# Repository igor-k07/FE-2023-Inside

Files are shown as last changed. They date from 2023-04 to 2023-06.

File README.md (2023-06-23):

# Структура репозитория:<br>
1.3D – папка содержащая 3D модели, которые использовались для создания робота<br>
2.Src –  папка с файлами, которые используются для описания в README.md<br>
3.Видео – папка содержит видео работа нашей модели, которая проезжает по полю квалификацию и файлик с названием: «ссылка на ютьюб». Это ссылка ведет на наше видео про обьяснение работы робота и его составных частей в общем плане.<br>
4.Код – папка содержит код, который используется при работе робота<br>
	4.1 kvalifikacia.py– файл который используется для проезда трассы на этапе квалификации. В нем считывается изображение с камеры и передается управляющее воздействие на пайборд<br>
	4.2 main.py – загружаем его на пайборд. В нем приводятся в работу компоненты подключенные к пайборду на основе сообщения полученного с расберри<br>
	4.3 final.py – код находится в папке Код, используется для проезда финальной трассы<br>
	4.4 autostart- программа, которая ззапускается при загрузке при загрузке системы на расберри. В ней мы импортируем нужный файл для заезда<br>
	4.5 start_robot.py – программа, которая позволяет соеденится по вай-фай с расберри, и загрузить на нее программу с ноутбука. С помощью неё также можно увидеть изображение с камеры для отладки.<br>
	4.6 robotAPI.py  - файл, в котором содержится класс для получения изображения с камеры и его обработки. <br>
5.Технический журнал – папка хранит в себе три файла формата docx, файлы представляют собой документации и тщательное обьяснение работы робота. <br>
6.Фото – папка содержит фотографию разработчиков робота.<br>
# Обьяснение кода<br>
main.py – файл формата python, загружается на пайборд, с целью управления нижней части робота или же ходовкой. Немало важный смысл программы, это прием сообщений с расберри, в сообщении храниться информация о том с какой скоростью должен ехать робот, с каким углом поворачивать и включение светодиода. Конец каждого сообщения заканчивается символом $ этот символ означает конец предложения. Это программа является обязательной для загрузки иначе следуйщий код работать не будет.<br><br>
kvalifikacia.py – этот файл используется для загрузки в расберри. Предназначен для того что бы проехать голую трассу, без обьезда красных и зеленых препятствий, программа проезжает 12 кругов и останавливается в том месте, откуда начинала движение.<br><br>
final.py – файл используется для проезда трассы, загружается в расберри. Предназначен для того что бы роехать 12 кругов и обьехать красные припятствия с правой стороны, а зеленые с левой стороны. <br><br>
robot_API.py – файл используется в качестве помошника в управлении камерой. Эта программа позволяет выделать на датчиках робота области интереса, обводить контуры и считывать определять hsv.<br><br>
 start_robot.py – программа позволяет увидеть всё то что видит робот, рассмотреть области интереса и обводимые контуры. Программа используется для удобной работы с роботом и его отладки. С помощью программы мы загружаем в робота программу.<br><br>
autostart - программа хранится на расбери и хранит в себе небольшой код, в котором указывается программа которую нужно включить. <br>

# Загрузка программы на пайборд<br>
На пайборд загружается только одна программа с названием main.py. Этот файл отвечает за получение сообщения для пайборда от расберри. Загрузка файла main.py является обязательной, для того что бы работали дальнейшие программы. Что бы загрузить на пайборд программу мы делаем:<br>
	1. Скачиваем файл main.py с нашего гитхаба:<br>
		Путь до файла: Код/main.py<br>
2. Подключаем пайборд к компьютеру с помощью микро usb, в проводнике пайборд называется PYBFLASH: <br>
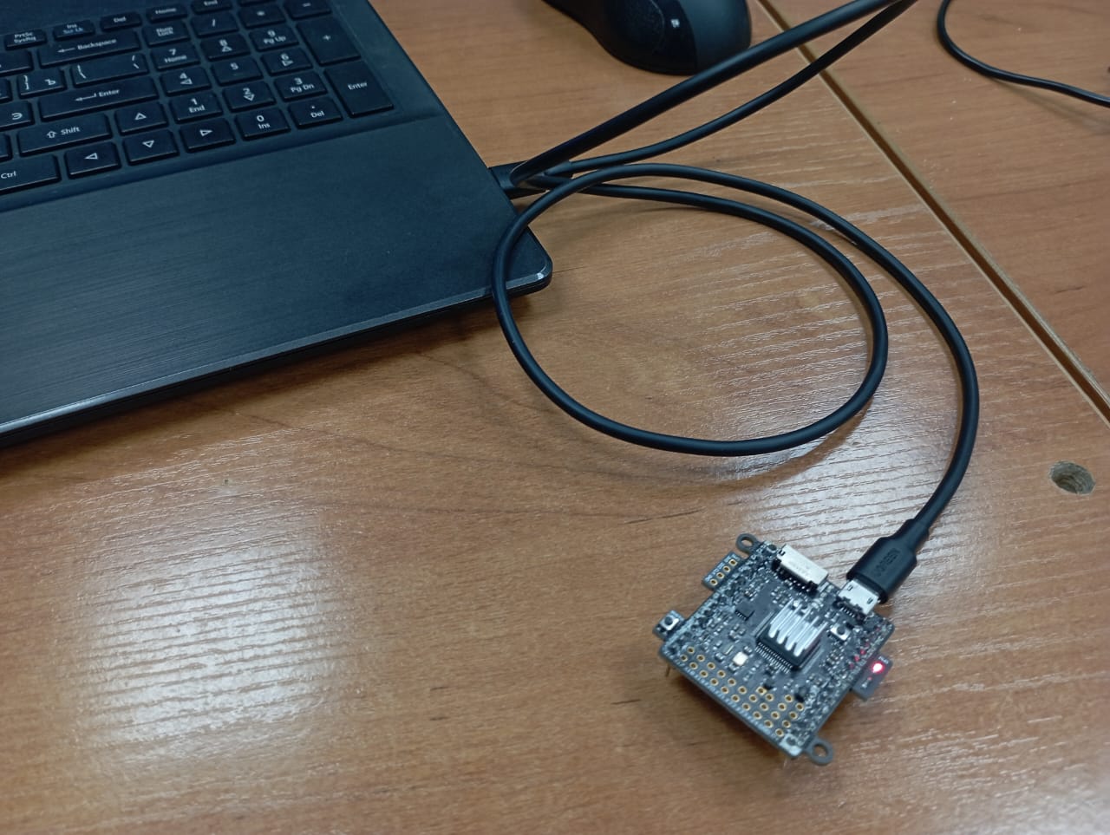
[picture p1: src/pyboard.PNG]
<br>
3. Открываем в проводнике наш пайборд:<br>
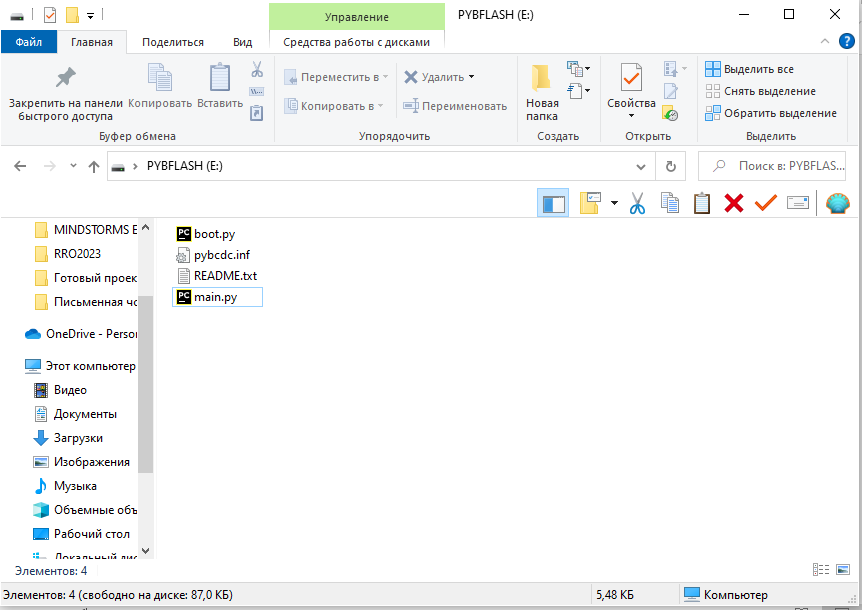
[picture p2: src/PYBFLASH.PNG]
<br>
4. Перекидываем файл main.py, если в вашем пайборде уже есть файл main.py, как случилось у нас, то просто скопируте код с нашего файла main.py на гитхабе и вставьте его в файл main.py, который уже стоит у вас на пайборде. Если файла main.py на пайборде нет, то перекидывайте его на пайборд:<br>
<br>

# Загрузка файла на расберри с компьютера<br>
На расберии у нас загружаются две программы kvalifikacia.py или final.py взависимоти от типа заезда, квалификации или финала. Они загружаются по одному алгоритму. Разберем его на примере загрузки квалификации, описанном ниже.
1. Сначала скачиваем бесплатную программу PyCharm с официального сайта. <br>
2. Скачиваем с нашего гитхаба файл start_robot.py, RobotAPI.py и файл kavalifikacia.py<br>
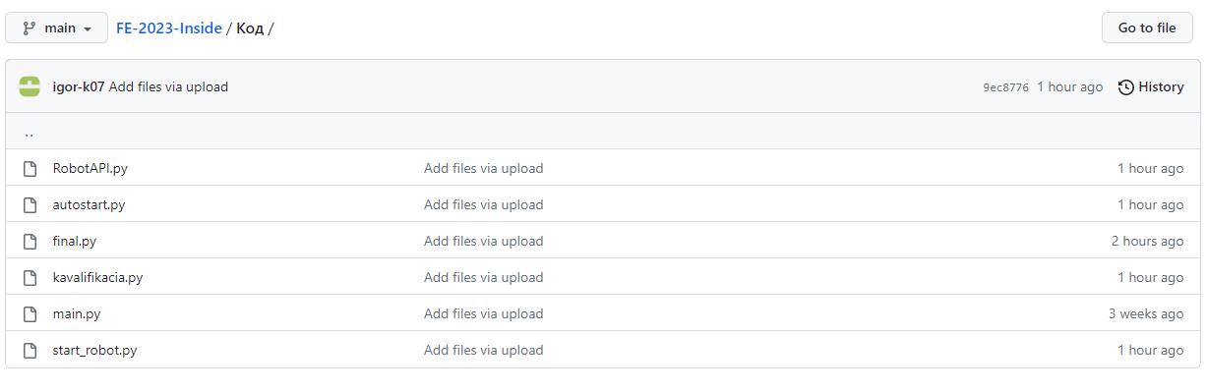
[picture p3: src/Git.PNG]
<br>
ВАЖНОЕ ПРИМЕЧАНИЕ! Скаченные файлы должны лежать в одной папке, советую создать отдельную папку и загрузит туда скаченные файлы!<br>
3.  С помощью правой кнопки мыши открываем файл start_robot.py в программе PyCharm. <br>
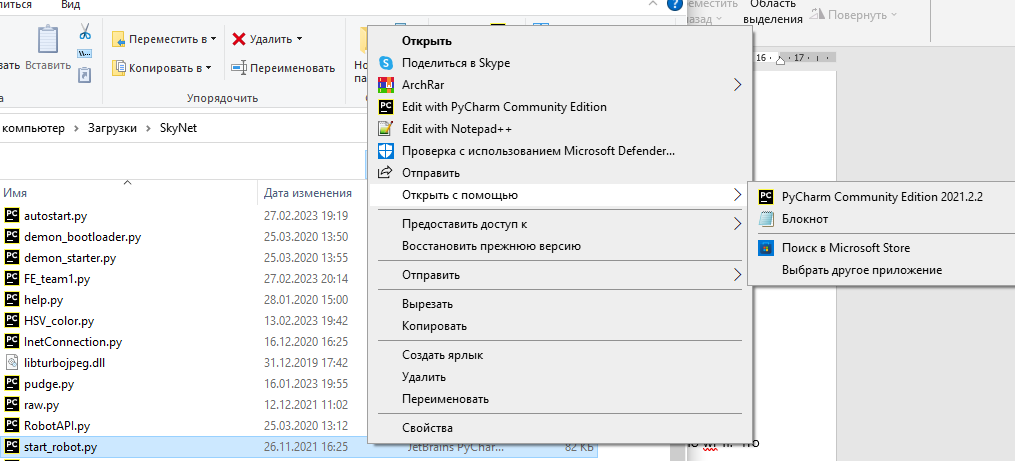
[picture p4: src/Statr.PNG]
<br>
4. Когда программа открыла код, нужно скачать библиотеки, которых у вас нет.<br>
5. Теперь с помощью правой кнопки мыши нажимаем на зеленную кнопку старта.<br>
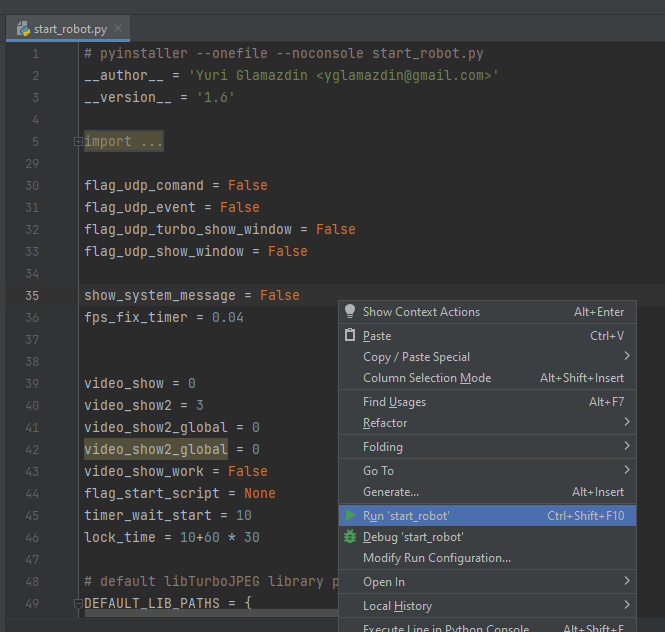
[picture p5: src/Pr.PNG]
<br>
6. У нас открывается окно. Теперь нужно подключиться к нашему роботу по wi-fi. Что бы это сделать запускаем робота и ожидаем его название в сети, наш робот называется Team1.<br>
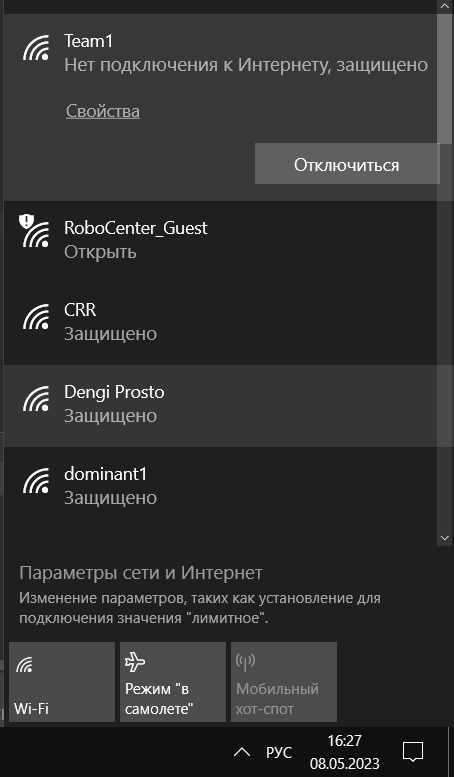
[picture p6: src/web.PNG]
<br>
7. когда произошло сопряжение с роботом нажимаем на кнопку connection и в выпадающем списке выбираем нашего робота.<br>
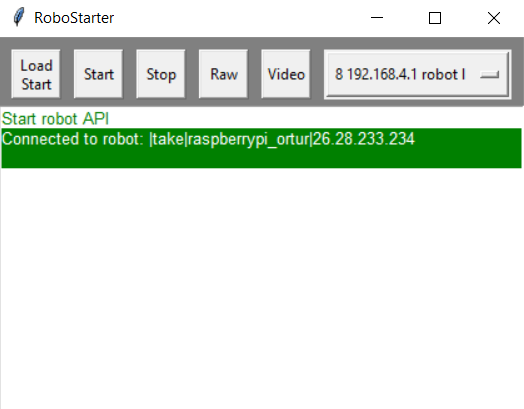
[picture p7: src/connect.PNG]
<br>
8. Программа подключилась к роботу, теперь откроем файл kavalifikacia.py. Что бы это сделать нажимаем кнопку Load, выбираем нужный файл kavalifikacia.py, нажимаем ОК.<br>
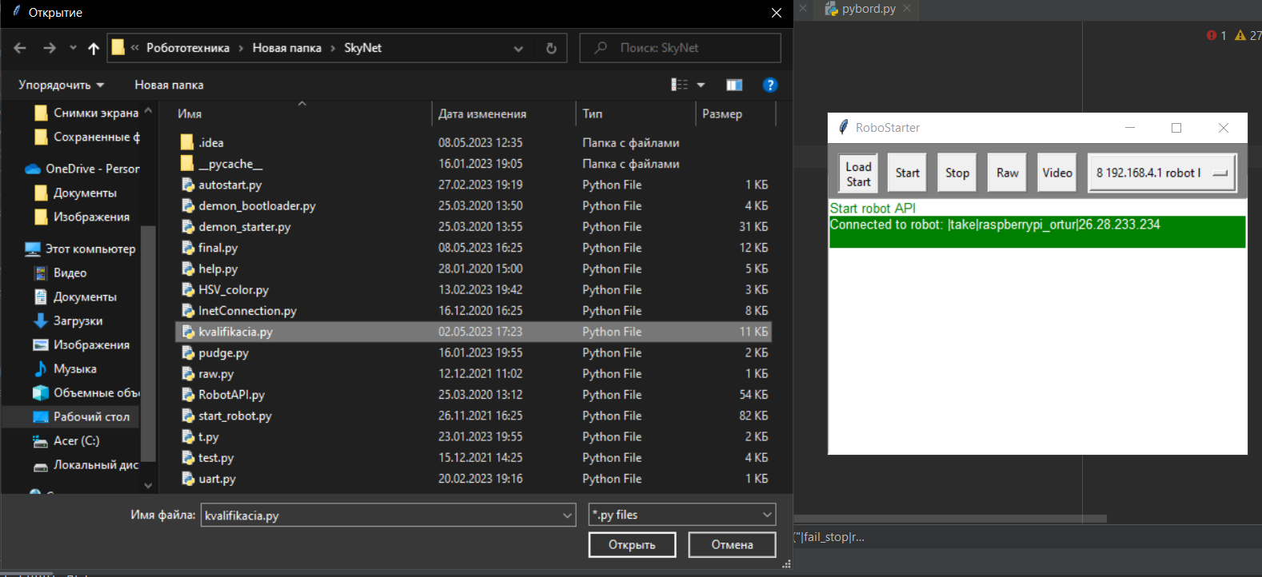
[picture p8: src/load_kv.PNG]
<br>
9. Теперь код загружен на нашего робота, что бы проверить код в действии нужно нажать в окне на кнопку video, что бы видеть то что на экране робота и запустить робота на поле, нажав на кнопку на его плате.<br>
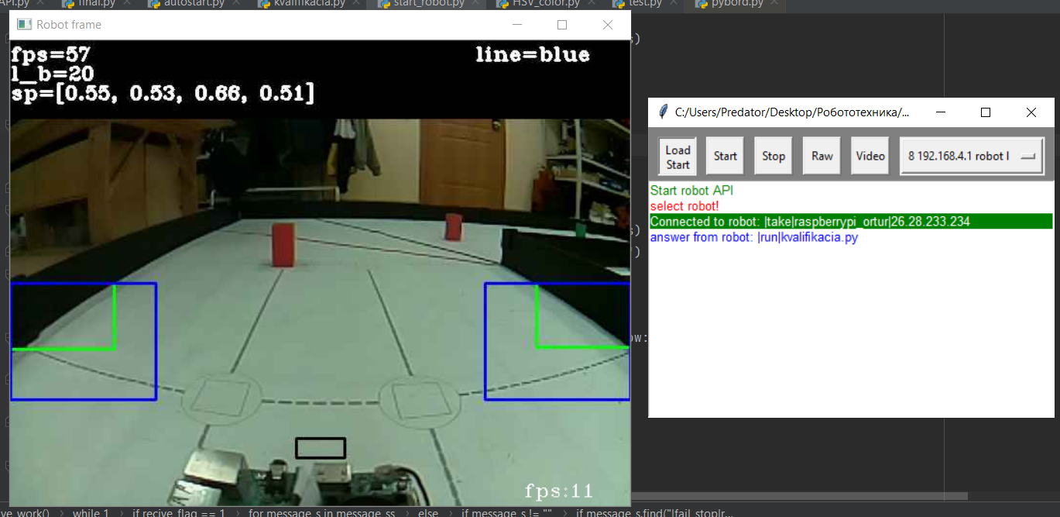
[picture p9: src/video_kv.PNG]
<br>
<br>
Автоматическая загрузка файла на расберри<br>
Для того чтобы нужный файл запускался на расберри сразу после включения робота, у нас существует файл autostart.py.<br>
Внутри него нужно импортировать нужный файл:<br>
import kvalifikacia - для квалификации,<br>
import final - для финала.<br>

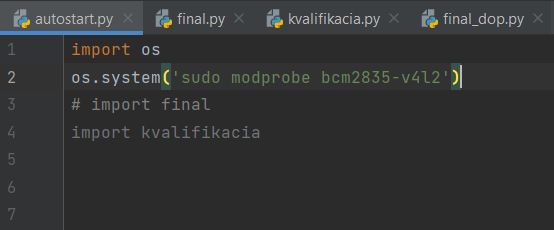
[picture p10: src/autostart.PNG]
<br>
В случае на картинке выше импортируется файл kvalifikacia.py, а импорт другого файла закомментирован.<br>
Загрузка autostart.py происходит по тому же алгоритму, как и при загрузке остальных файлов на расберри. После его загрузки, при запуске робота, на нем уже будет та программа которую мы импортировали. Остаётся лишь запустить её.

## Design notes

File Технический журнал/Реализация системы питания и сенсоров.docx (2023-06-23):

Реализации системы питания и сенсоров

1. Электропитание

При выборе источника питания мы исходили из того, что наш мотор потребляет 12 вольт. Мы также решили, что будем использовать три батарейки для обеспечения питания. Из тех компонентов, что у нас мы были, мы выбирали из двух видов аккумуляторов удовлетворяющих нашим требованиям, а именно литий-ионные аккумуляторы 14500 и 18650. Мы сравнили их характеристики и по ним выбрали наиболее нам подходящие. Сравнение характеристик представлено в таблице 1.

Таблица 1. Сравнение аккумуляторов

Характеристики
Тип аккумулятора | Аккумулятор 14500 | Аккумулятор 18650
Размер | Диаметр – 14 мм, длина – 50мм | Диаметр – 18,4 мм, длина – 65мм
Номинальная ёмкость | 850-1000 mAh | 2500-2850 mAh
Токоотдача | 1-2 А | 10 A
Номинальное напряжение | 3,7V | 3,7V

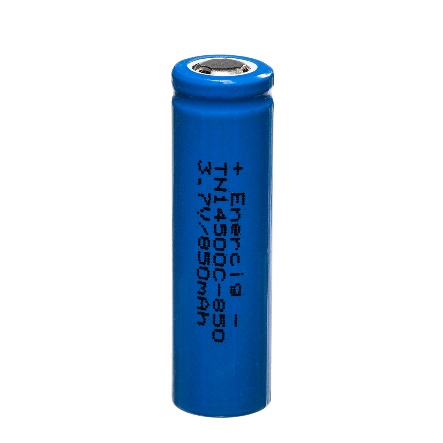
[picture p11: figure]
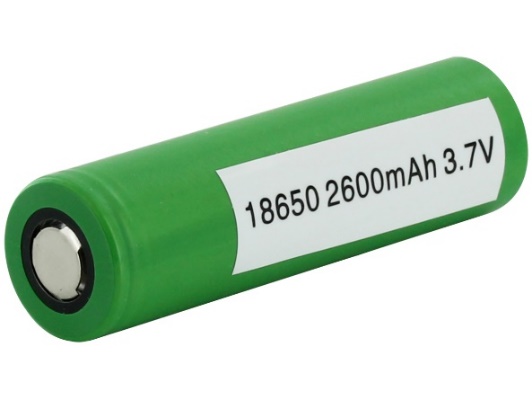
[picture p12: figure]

Фото

Исходя из характеристик мы все же решили выбрать аккумуляторы 18650, т.к не смотря на то, что их размер больше, они обладает почти в два раза большей емкостью чем аккумуляторы 14500, из-за чего он смогут проработать дольше до разрядки, а также они обладают большей токоотдачей, которая напрямую влияет на то, какой крутящий момент сможет развить мотор. Все это позволит нашему роботу ездить дольше и быстрее.

Для закрепления батареек мы использовали держатель для 3-х литий-ионных батареек, который мы прикрутили к нашему корпусу.

2. Сенсоры

При создании робота мы не использовали какие-либо отдельные датчики, нашим основным сенсором является камера. Мы получаем с неё изображение и выделяем на нем области интереса, которые и является нашими сенсорами. У нас созданы сенсоры для черных бортиков, синей и оранжевой линий, и знаков. Камеру нам тоже пришлось выбирать. В данном случае мы выбирали, из трех возможных камер, которые нам были предоставлены. Характеристики камер представлены в таблице 2.

Таблица 2. Сравнение камер

Характеристики
Название камеры | RPi Camera | RPi Camera (I) | RPi Camera (B)
Диафрагма | 2,9 | 1,8 | 2,0
Фокусное расстояние | 3,29 мм | регулируемое | 6 мм(регулируемое)
Угол обзора | 72 градуса | 170 градусов | 75 градусов
Размеры | 25x20 мм | 32х32 мм | 32х32 мм
Разрешение матрицы | 5 Мп | 5 Мп | 5 Мп

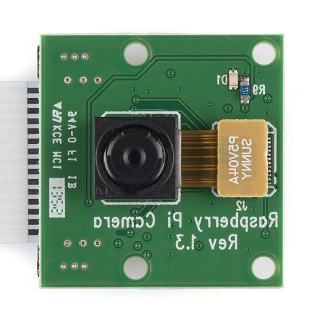
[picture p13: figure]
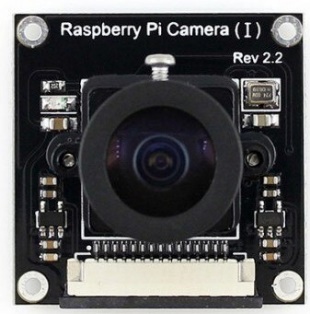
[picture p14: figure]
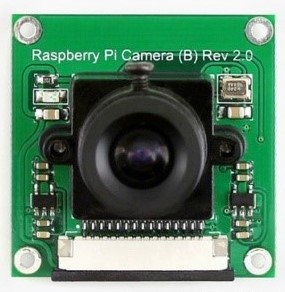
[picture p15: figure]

Фото

В итоге мы остановились на выборе камеры RPi Camera(I) с линзой “рыбий глаз”. Её главным плюсом для нас является ее большой угол обзора, почти в 2,5 раза больше чем у двух других камер. Благодаря такому углу обзора мы можем видеть всю обстановку на поле в целом, в частности нам открывается хороший обзор на бортики поля, благодаря которым наш робот двигается правильно. В случае узкого угла обзора движение робота могло бы быть хуже, ведь поле и бортики не было бы видно так как мы бы хотели. В остальном она не сильно отличается от других двух камер, можно лишь отметить, что в отличие от маленькой камеры RPi, камера RPi(I) как и камера RPi(B) имеют регулируемое фокусное расстояние, что может быть достаточно полезно. Минусом выбранной нами камеры является только лишь размер, она чуть больше в ширину и длину и сильно больше в высоту, из-за её объектива. Но размеры нам совсем не мешают, ведь у нас сделано отдельно крепление для камеры, которая закреплена сверху и немного под углом. Крепление под углом дает нам обзор на поле, для распознавания объектов перед самим роботом, а не только впереди с верхнего обзора.

3. Электроника

На нашем роботе, а точнее на плате расположено много других компонентов, все они, и их описание и предназначение представлено в таблице 3.

Таблица 3.Электронные компоненты

Название компонента | Фото компонента | Описание

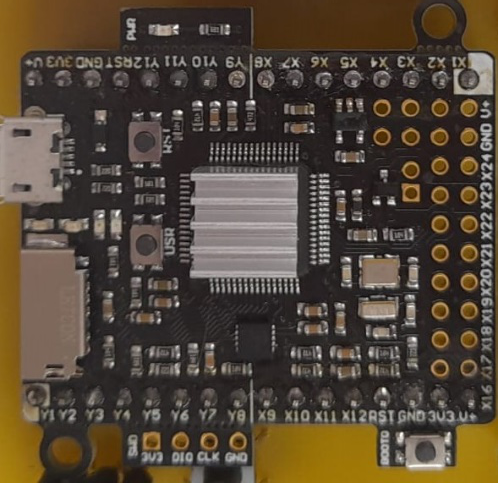
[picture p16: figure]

Pyboard | | Микроконтроллер, отвечает за работу почти всех компонентов на плате и всего робота в целом, на основе информации, полученной от микрокомпьютера Raspberry

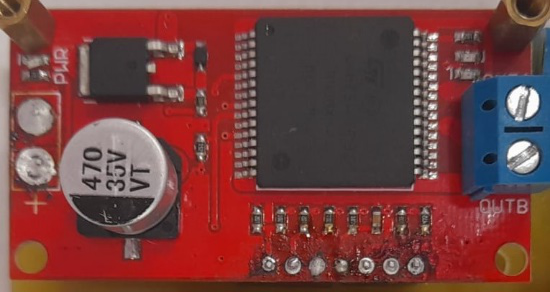
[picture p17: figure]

Модуль RM018. Миниатюрный драйвер шагового двигателя VNH2SP30 | | Отвечает за управление коллекторным мотором

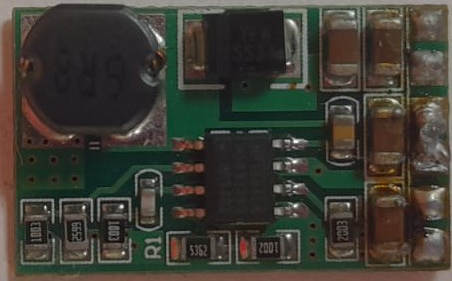
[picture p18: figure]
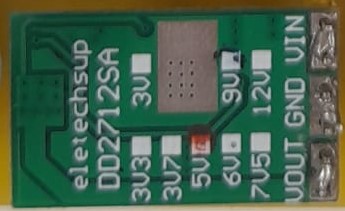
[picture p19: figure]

Модуль преобразователя TZT DD2712sa, понижающая плата регулятора напряжения | | Снижает напряжение входящее на pyboard с 12 до 5 вольт, для корректной работы микроконтроллера.

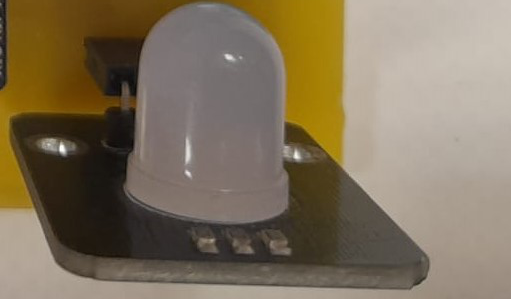
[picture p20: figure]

RGB Светодиод | | Используем один светодиод, но RGB, для того чтобы показывать состояния робота с помощью цвета

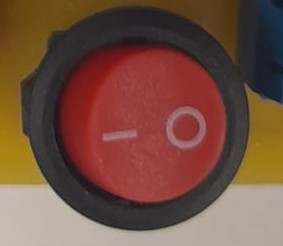
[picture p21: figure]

Ключ | | Замыкает и размыкает цепь (Включение\Выключение робота)

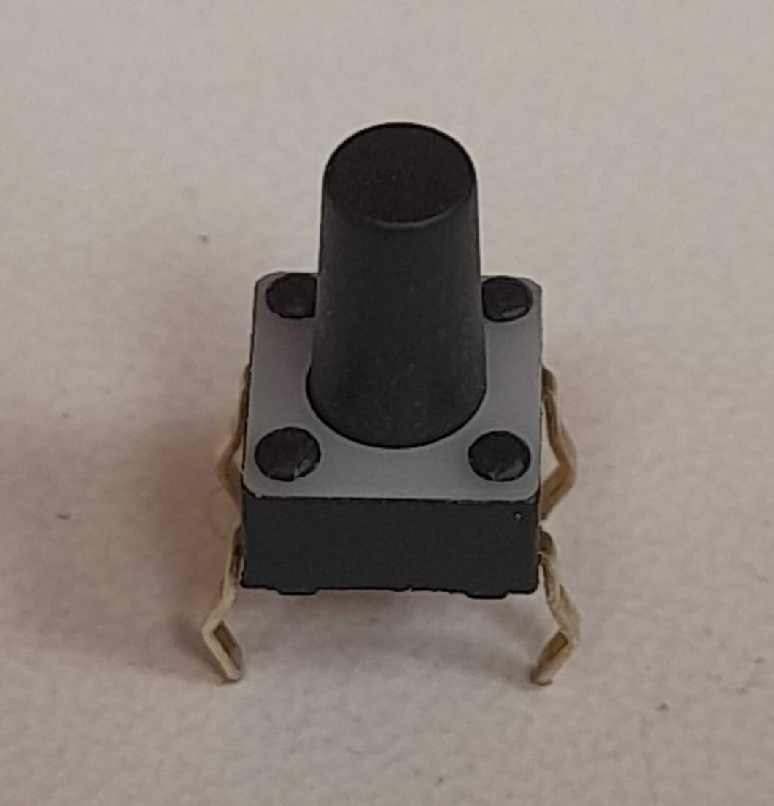
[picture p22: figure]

Кнопка | | Отвечает за включение программы на pyboard(одно нажатие запуск, нажатие второй раз останавливает программу)

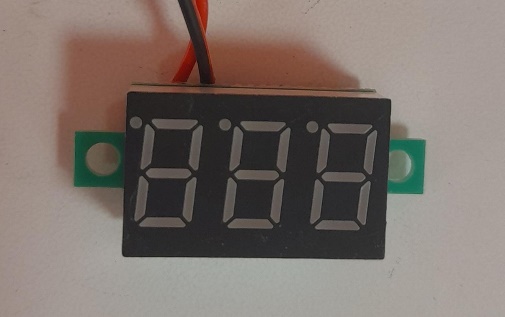
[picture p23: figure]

Вольтметр | | Служит для отслеживания нужного напряжения на участке цепи

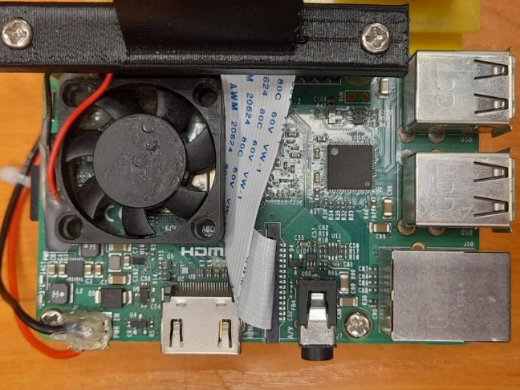
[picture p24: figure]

Raspberry | | Микрокомпьютер, к нему подключена камера, информацию с которой он обрабатывает, и нужные значения передает на pyboard

На фотографии ниже представлена электронная палата в целом.

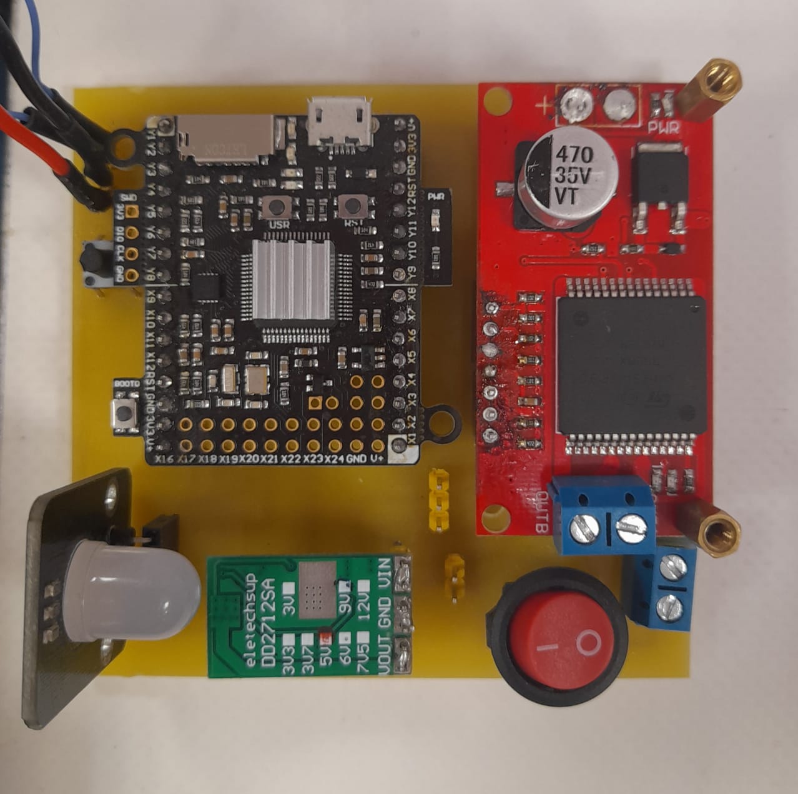
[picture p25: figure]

На ней стоит обратить внимание на желтые штырьки три желтых штырька используются для подключения к плате серво привода, а другие два – для подключения вольтметра. У вольтметра и серво на конце проводов имеются специальные коннекторы для подключения к этим штырькам. мы сделали так для удобства замены компонентов, ведь так их гораздо легче снять, чем пытаться заменить в паяные напрямую компоненты. Также с это целью у нас установлены клемники на плате и на драйвере.

Подключение Pyboard c Raspberry происходит через пины Y1 и Y2, у которых имеется UART. Эти пины с пинами RX и TX микрокомпьютера Raspberry, соединяют провода, припаянные к штырькам в правом верхнем углу платы. Там же припаяны красны провод - плюс(+) и черный провод -минус(-), соединяющие пины GND и +5V микроконтроллера pyboard и микрокомпьютера raspberry.

Более подробную информацию о подключении всех компонентов на плате можно увидеть на электрической схеме, составленной нами в онлайн редакторе easyeda и представленной ниже.

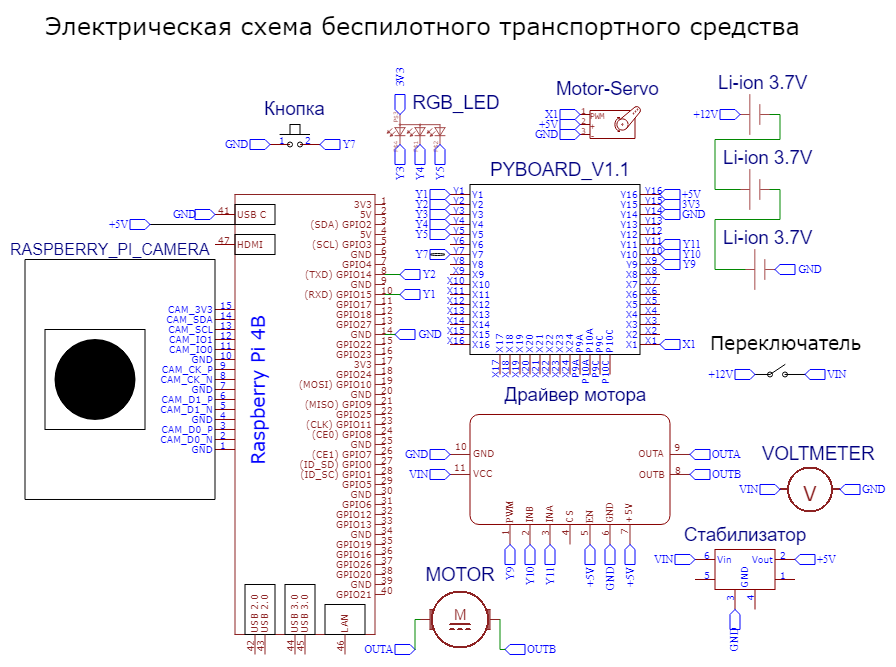
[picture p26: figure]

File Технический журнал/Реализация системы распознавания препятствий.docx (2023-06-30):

Реализация системы распознавания препятствий

Для того чтобы робот мог выполнять все поставленные задачи, мы написали программу на языке python. Разработку мы вели в среде Pycharm. Мы создали на изображении камеры 4 области интереса, изображенных и подписанных на изображении ниже, каждая из которых отвечает за отдельную задачу нашего алгоритма. Тем самым его можно разделить на несколько пунктов: движение по чёрным бортам, поворот, объезд знаков, разворот и финиш. Каждый пункт рассмотрен более подробно ниже.

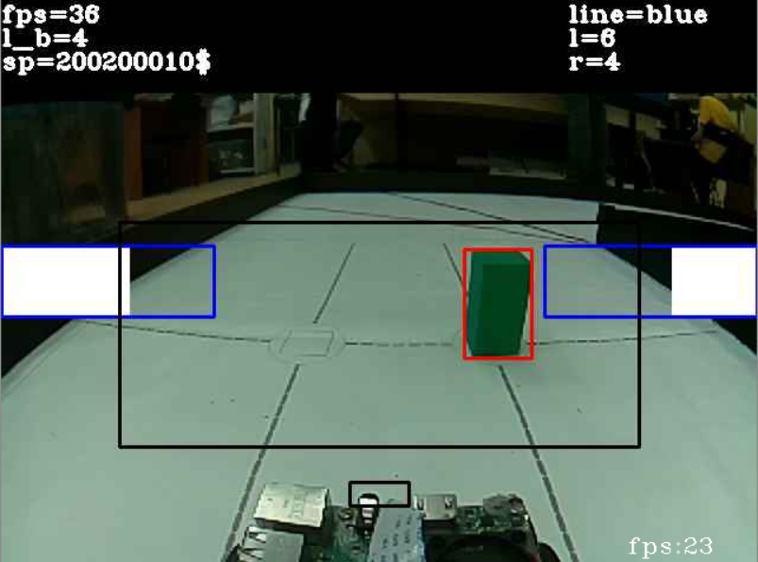
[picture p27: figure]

1. Движение по черным бортам

Движение по бортам осуществляется с помощью областей интереса №1, №2 и функций pd(), drz() и dlz(). В последних двух наши области интереса разбиваются на 20 частей и на каждом кусочке находим черный. Для каждого датчика существует массив в котором записывается либо 1 если есть черный контур в данной области или 0 если его нет. Самая крайняя единица в массиве является краем контура черного, индекс которой, обозначенный как i, в массиве и равен значению нашего датчика.(В левом датчике находим индекс крайней правой единицы и значение датчика равно i, для правого датчика находим индекс левой крайней единицы, и значение датчика равно 19 – i).

Основной функцией, которая отвечает за само движение, является функция pd() – пропорционально-дифференциальный регулятор. В ней мы определяем угол поворота по формуле – servo = k * e + * (e - eold), в которой servo – значение угла поворота серво мотора, k – коэффициент пропорциональности, e – ошибка, которая равна разнице между показанием левого и правого датчика (e = dl - dr), а eold – это ошибка прошлых показаний. Также в функции pd() у нас есть ограничение на максимальный угол поворота сервомотора от -50 до 50 и проверка на случай, при котором на датчиках мы не видим черный цвет. В таком случае мы в зависимости от направления движения поворачиваем на 20 или на -20, в зависимости от направления.

2. Поворот

Поворот осуществляется благодаря области интереса №3 и функции dlin(). Именно в этой области интереса мы находим цвет линии которую мы проезжаем первой, и он будет являться ориентиром в направлении нашего движения. Зная направление мы можем повернуть в нужную сторону, и выполнить другие алгоритмы связанные с направлением движения. Мы также считаем количество пройденных поворотов(линий) и записываем их в переменную circle.

3. Объезд знаков

В ней мы отслеживаем знаки впереди робота и их цвет. Алгоритм обнаружения знаков реализован в функции datz(), в ней мы находим контур увиденного знака, и сохраняем его размеры. В зависимости от цвета увиденного знака, вызывается либо функция pdzr(), для красного знака, либо функция pdzg(), для зеленого знака.

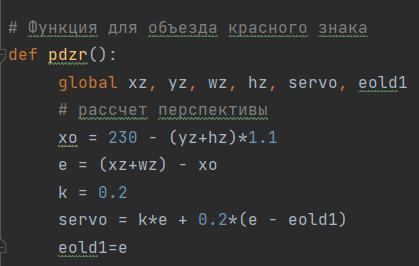
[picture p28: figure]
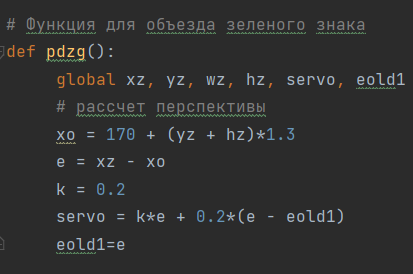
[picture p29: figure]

В этих функциях реализован алгоритм объезда знаков. Он работает по принципу пропорционально-дифференциального регулятора, только он заставляет робота ориентироваться не по бортикам, а по контуру знака. В случае красного знака ошибка показаний высчитывается по формуле e = (xz + wz) – xo, где xz это самая левая координата x знака, wz – ширина контура, а xo – переменная, в которой учитывается перспектива, относительно координаты y, и высчитывается она по формуле xo = 230 – (yz + hz) * 1,1 (yz – координата y нижней точки знака, hz – ширина контура знака, а 230 и 1,1 – подобранные коэффициенты). Для зеленого знака ошибка высчитывается как e = xz – xo, а учет перспективы идет по формуле xo = 170 + (yz + hz) * 1,3. Таким образом, объезд зеленого знака происходит с левой стороны, а красного справа. Также в случае если робот не видит никакого знака, то он едет по обычному регулятору pd().

4. Разворот

После второго круга, в случае если последний кубик до этого был красного цвета, у нас стоит цель развернуться и проехать последний круг в противоположную сторону. Для этого у нас создана функция razvorot(). В ней в зависимости от вида разворота, ближе к внешнему или внутреннему бортику, выполняем необходимый алгоритм. Также во время разворота все датчики перестают работать, чтобы не увидеть лишних помех, и не насчитать лишних поворотов.

5. Финиш

Финиш робот производит только после проезда 12 перекрестков, то есть когда circle = 12, в этом случае мы запоминая до этого время между поворотами, проезжаем половину этого времени и останавливаемся как раз в зоне старта.

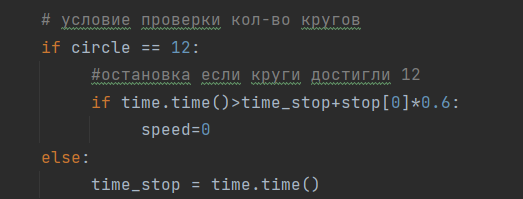
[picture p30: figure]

6. Общий алгоритм движения робота.

Бесконечный цикл:

Считываем изображение

Если не выполняется разворот:

Считываем линию на кадре

Считываем левый бортик на кадре

Считываем правый бортик на кадре

Считываем знак на кадре

Если робот находится в движении:

Если не видим знак:

Едем по регулятору pd()

Если увидели красный знак:

Едем по регулятору pdzr()

Если увидели зелёный знак:

Едем по регулятору pdzg()

Иначе:

Робот стоит на месте и колеса стоят ровно

Если проехали 8 поворотов и последний кубик был красный:

Разворот в другую сторону

Если проехали 12 поворотов:

Проезжаем примерно половину времени между поворотами

Останавливаемся

Иначе:

Запоминаем время

(https://robofinist.ru/article/66)

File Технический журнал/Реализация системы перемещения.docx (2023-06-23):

Реализация системы перемещения

1. Выбор моторов

Движение нашего робота обеспечивает 2 мотора. Мы используем один коллекторный мотор и один серво.

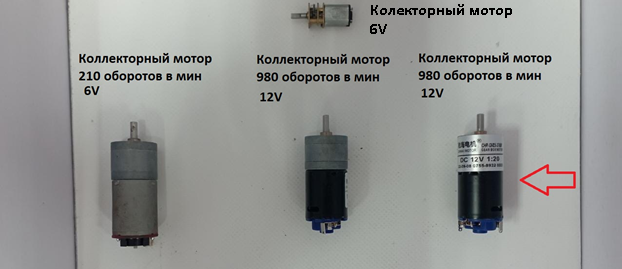
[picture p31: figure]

У нас было несколько видов моторов на выбор: 4 коллекторных (все представлено на картинке выше). Коллекторный мотор мощностью 500 оборотов в минуту мы не взяли, потому что он слишком маленький и слабый для нашей модели, он бы не смог обеспечить нашему роботу достаточно быстрое движение (находится ваше остальных моторов по центру). Что касается других коллекторных моторов, из них на выбор давали мотор мощностью 210 оборотов в минуту и два мотора с мощностью 980 оборотов в минуту. Мы решили не рассматривать мотор мощностью 210 оборотов в минуту так как он не смог бы обеспечить нашему роботу достаточную скорость на поле. Мы остановились на выборе между двумя моторами мощностью 980 оборотов. Из них мы выбрали самый новый по дате изготовления мотор (отмечен на картинке красной стрелкой). Моторы на картинке расположены в возрастании по мощности. Коллекторный мотор приводит нашу модель в движение. Программа регулирует его мощность и направление движения (вперед или назад).

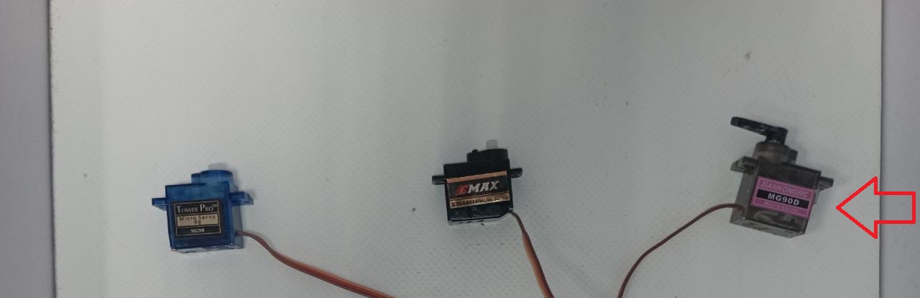
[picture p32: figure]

В качестве рулевой силы нам дали на выбор три серво мотора. Из них мы выбрали серво MG90D (на картинке отмечен красной стрелкой), потому что в отличии от других представленных на картинке выше мотор у него был железный редуктор, который бы обеспечил нашей модели долговечность механизма, бесперебойную и точную работу. Редуктор остальных моторов состоял из пластика, который в свою очередь мог легко привнести поломку модели. Снизу представленны характеристики на которые мы опирались в выборе мотора.

- Рабочее напряжение: 4.8V ~ 6.6V
- Крутящий момент:
  - 2.1 кг/см при 4.8V
  - 2.5 кг/см при 6.6V
- Скорость:
  - 0.10 сек/60 ° при 4.8V
  - 0.08 сек/60 ° при 6.6V
- Ход сервопривода: 90 ° (45 ° в каждую сторону)
- Материал шестерни: металл
- Тип серво-машинки: цифровой
- Вес: 13г

1. Выбор подвески автомобиля

У нас был выбор между вумя видами подвески: независимая подвеска и мосты.

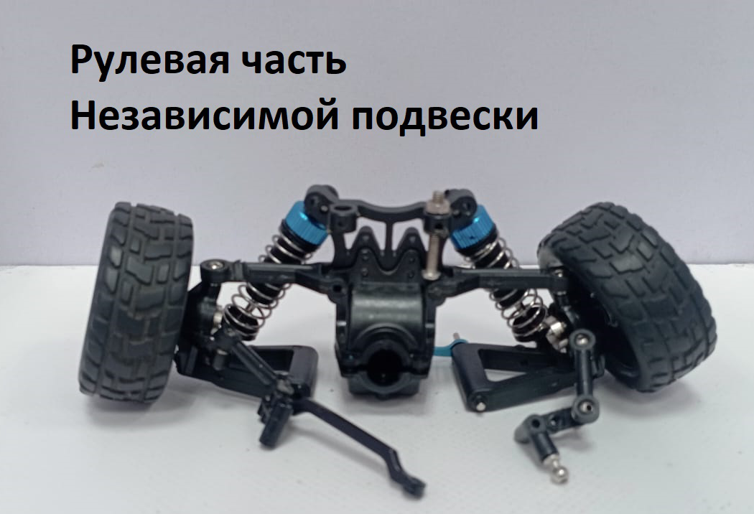
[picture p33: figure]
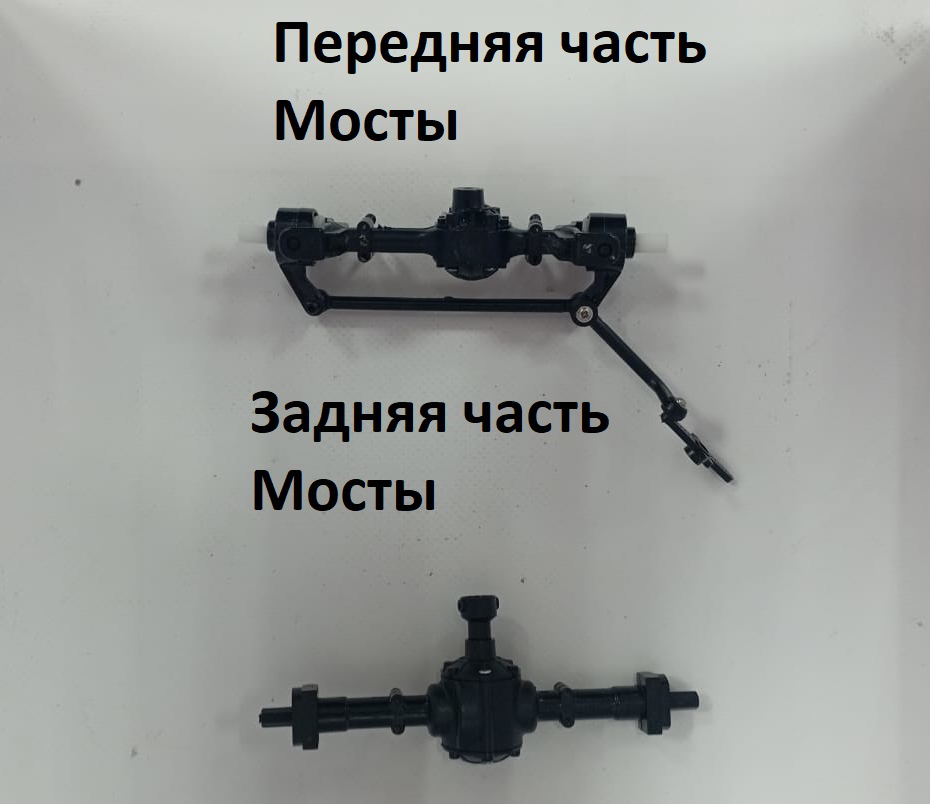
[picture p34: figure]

Мы сделали выбор в пользу независимой подвески, потому что в отличие от мостов в независимой подвески был механизм дефферинциала и, потому что каждое колесо имеет свое независимое состояние. Эти причины помогли нам сделать выбор в пользу независимой подвески.

3. Выбор колёс


Сначала мы решили использовать стандартные колеса, которые прилагались к нашей шасси, но пришли к тому, что они слишком изношенные и, бывали моменты когда они пробуксовывали из-за плохого сцепления с трассой. Что бы такого больше не происходило мы решили взять шины из набора ЛЕГО МАИНДСТОРМС и самим разработать диски под эти шины. Как я считаю шины лего самые качественные и износостойкие, поэтому мы их и взяли. Разработка дисков не составили труда, мы измерили диаметр всей шины, глубину прорезов под неё и пришли к готовому варианту, который стоит в нашей модели сейчас. 3D модель диска можно найти и скачать в папке 3D, 3D модель диска называется «Колесо.slt» и уже сразу готова под печать.

4. Создание рамы для робота

Мы решили что все компоненты движения будут на основной раме. Исходя из размеров компонентов, и их формы мы сделали следующую раму. На картинке снизу представлена рама нашего робота, цифрами подписаны ключевые компоненты. 3D модель нашей рамы вы можете найти в папке 3D на нашем гитхабе, 3D модель рамы находится в файле «Основа(Нижний этаж).stl» и уже сразу готова под печать. Сверху над сервоприводом, с помощью шурупов, прикручена пластина, она обозначена на картинке цифрой 7 и служит для усиления крепления серво в пазе. Пластина под номером 8 служит дополнительным укреплением для передней части. Вы можете найти 3D модели пластин на нашем гитхабе в папке 3D, они находятся в одном файле с названием «Пластина.stl» и уже сразу готова под печать.


5. Механическая схема

Ниже представлена механическая схема нашего шасси, в рамке вынесены обозначения всех компонентов на схеме. Голубыми кружками обозначены подвижные места. Сервомотор управляет рулевой системой, и отвечает за поворот нашего робота в пространстве. Мотор заднего привода приводит в движение дифференциал, который в свою очередь реализует независимое движение колес, и более эффективное движение по полю.


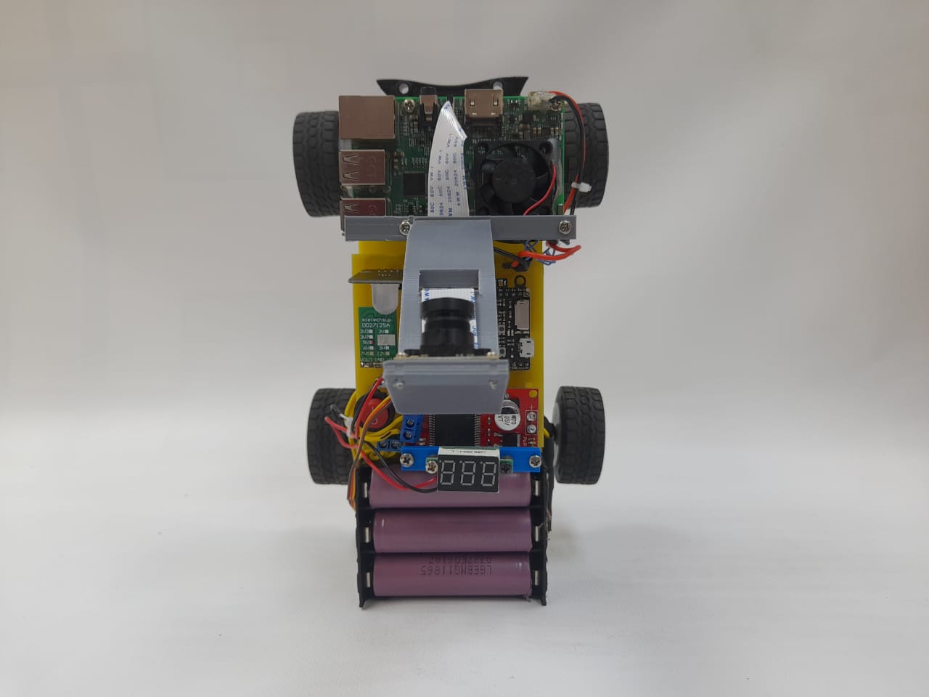
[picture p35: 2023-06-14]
Фото робота/Вид сверху.jpeg

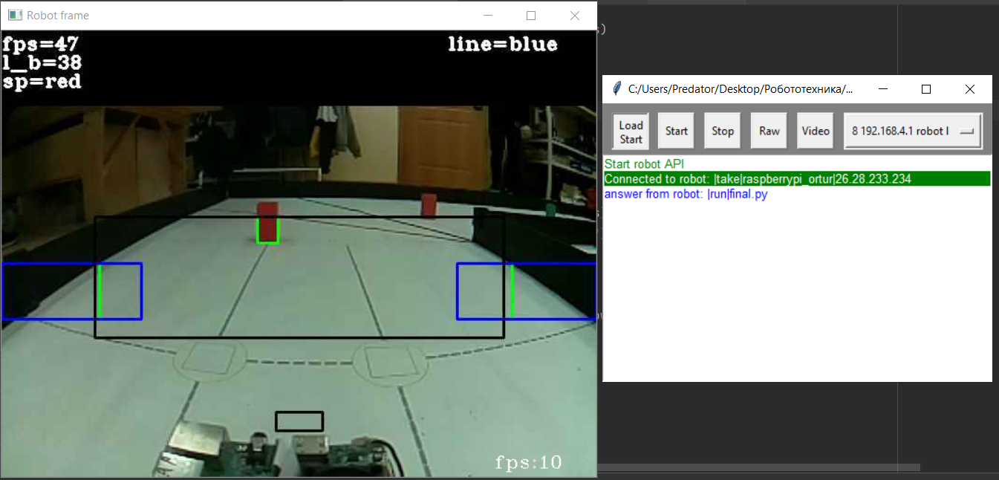
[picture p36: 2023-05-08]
src/video_final.PNG

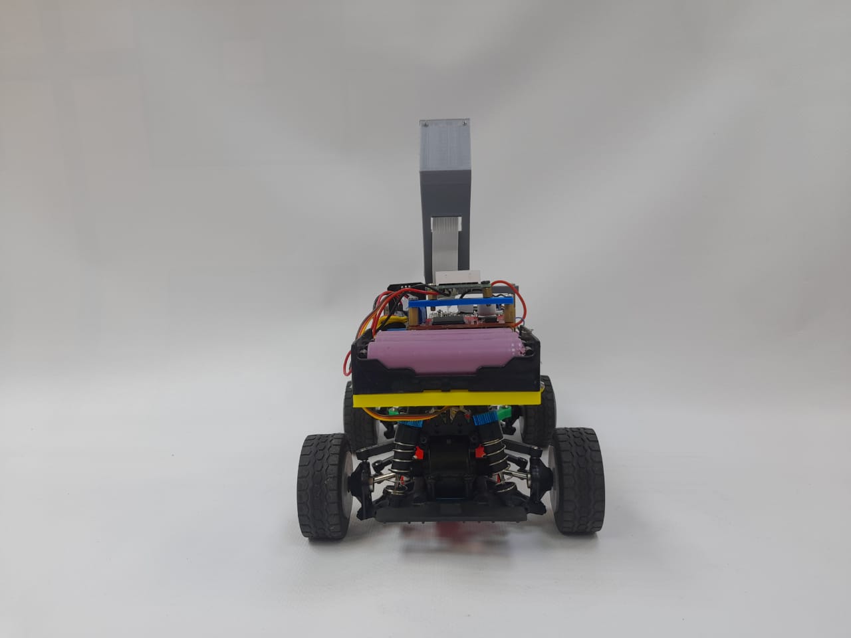
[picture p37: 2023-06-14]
Фото робота/Вид сзади.jpeg

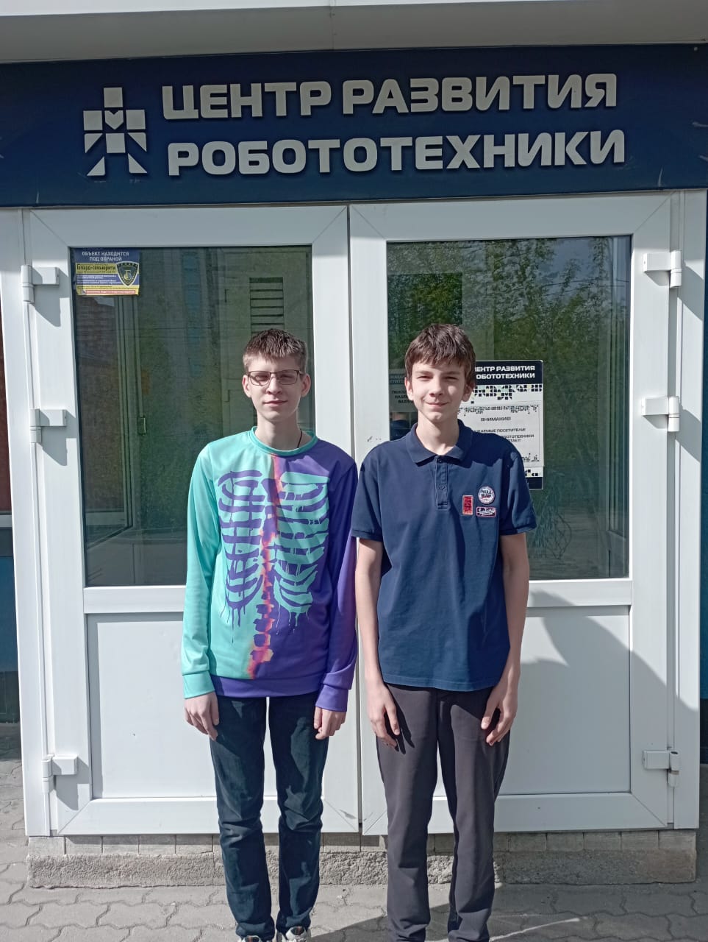
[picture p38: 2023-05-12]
Фото команды/Официальная фотография.jpeg

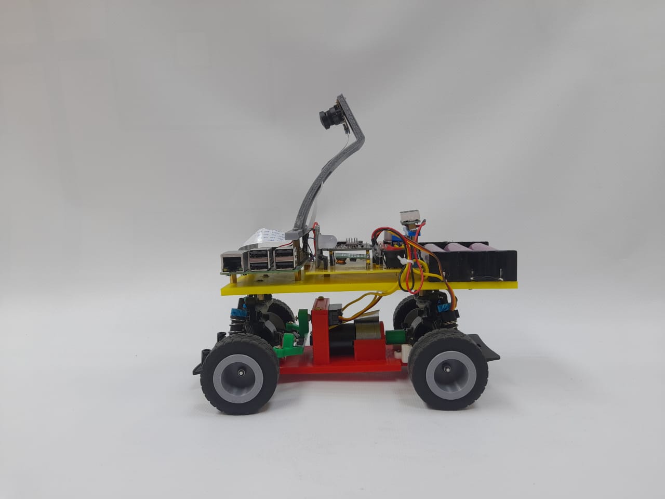
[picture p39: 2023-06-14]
Фото робота/Вид слева.jpeg

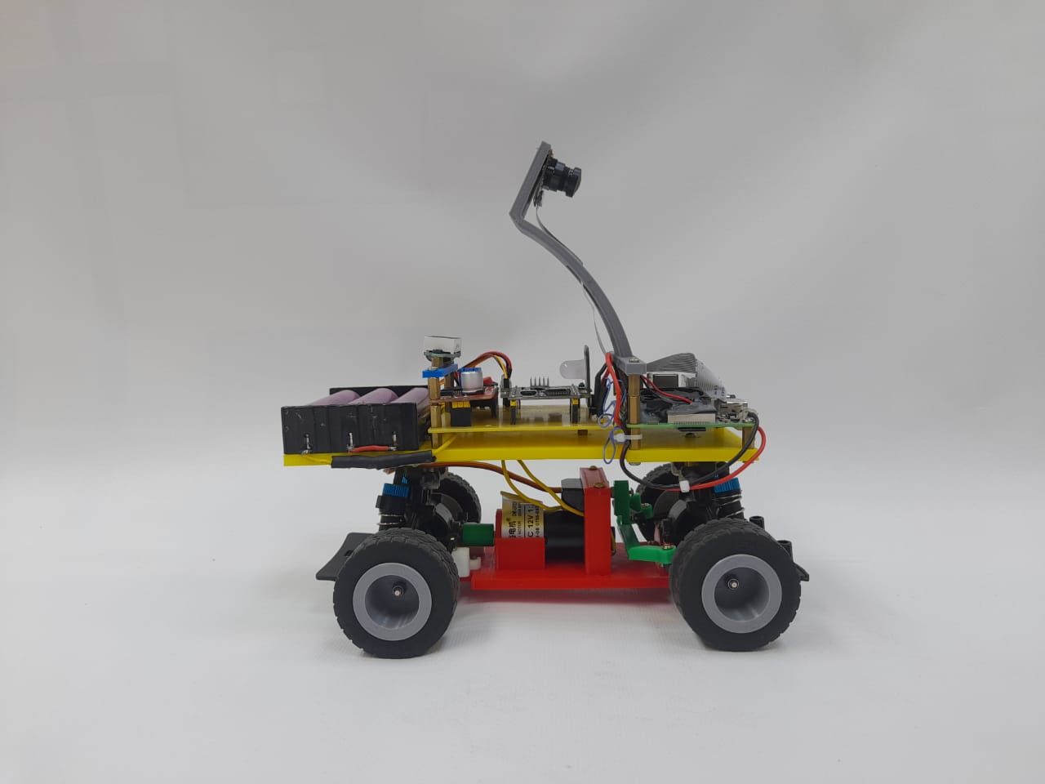
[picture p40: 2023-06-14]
Фото робота/Вид справа.jpeg

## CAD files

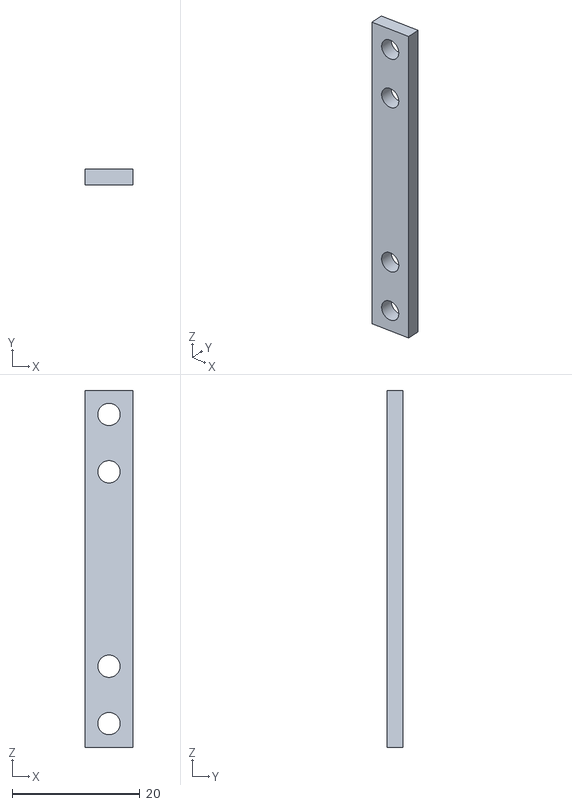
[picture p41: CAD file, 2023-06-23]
3D/пластина для вольтметра.stl
7.50 x 2.50 x 56.0

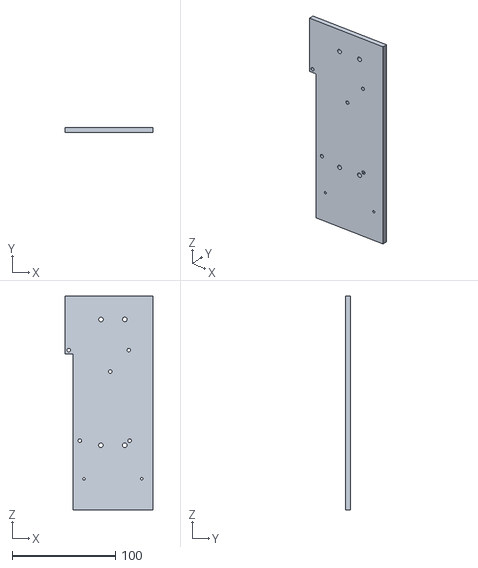
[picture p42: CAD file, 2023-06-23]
3D/осова(верхний этаж).stl
85.0 x 5.00 x 207.5

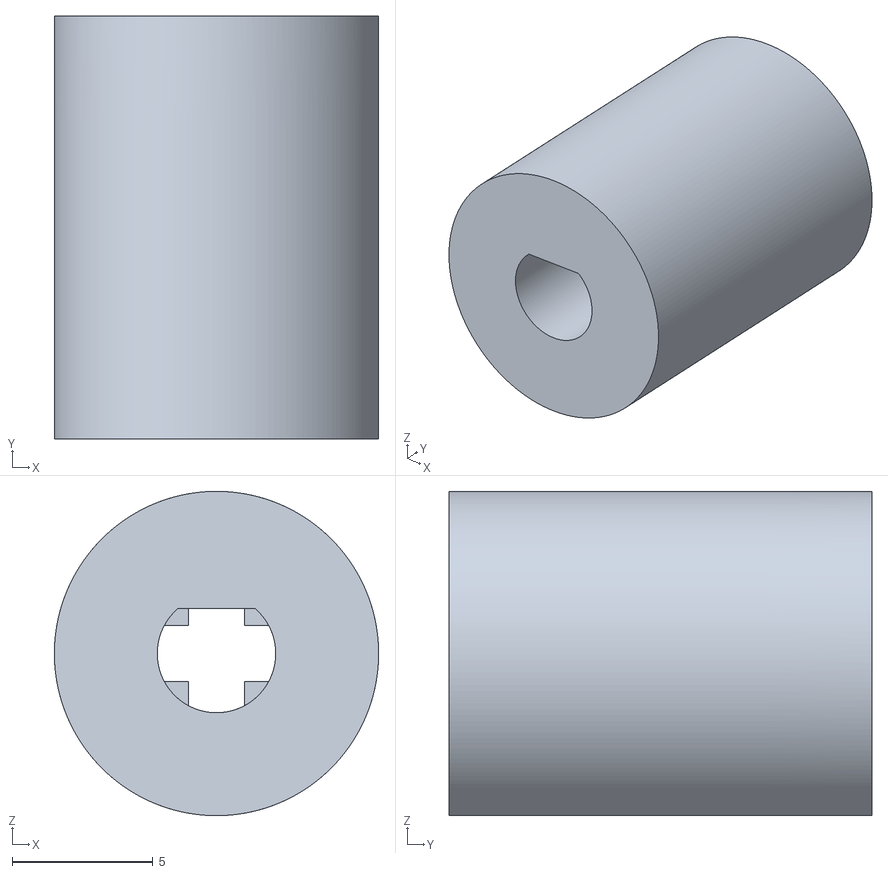
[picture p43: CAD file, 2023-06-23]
3D/муфта.stl
11.5 x 15.0 x 11.5

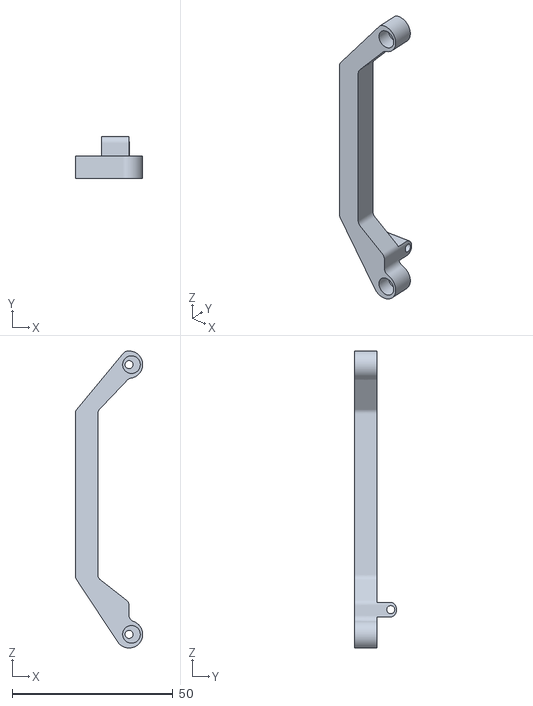
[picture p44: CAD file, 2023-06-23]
3D/рейка.stl
21.0 x 13.0 x 92.5

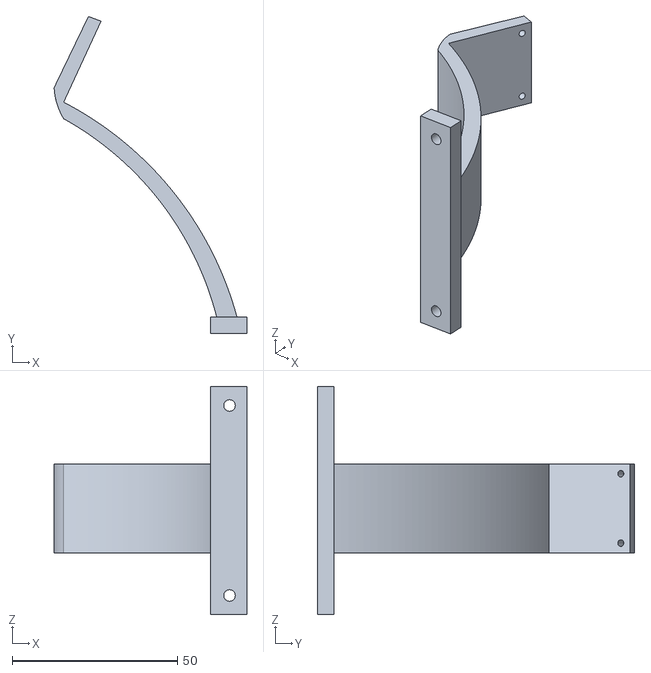
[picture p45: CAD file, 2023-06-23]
3D/крепление для камеры.stl
58.3 x 95.9 x 69.0

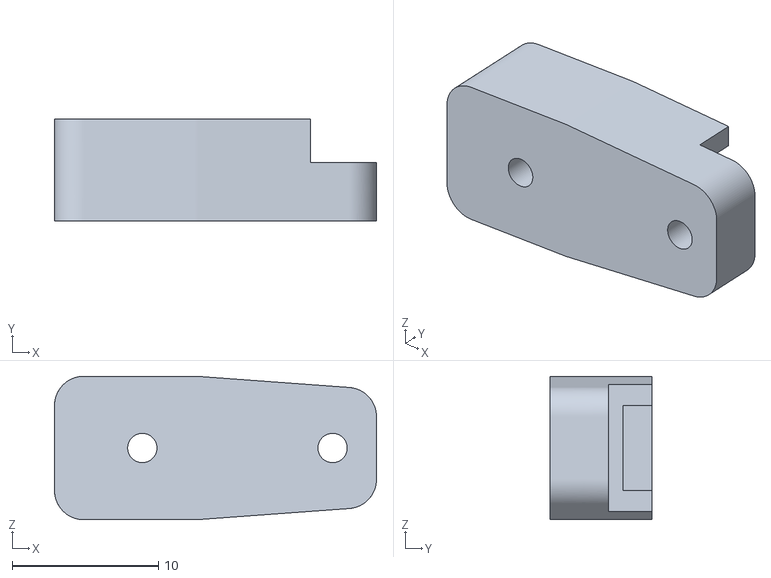
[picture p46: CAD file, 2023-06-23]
3D/качалка для сервомотора.stl
22.0 x 7.00 x 9.80

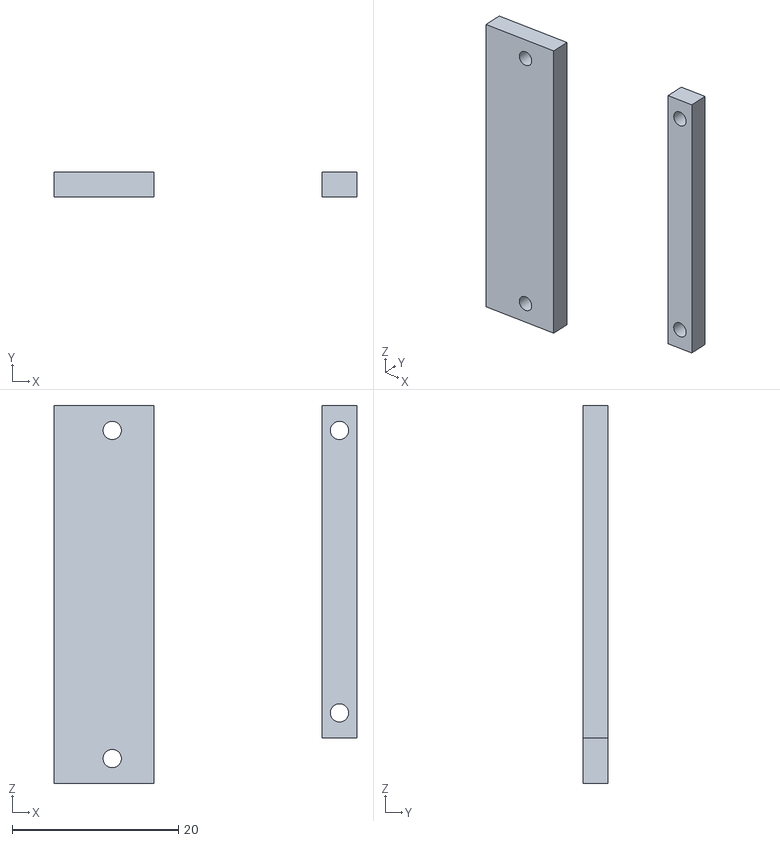
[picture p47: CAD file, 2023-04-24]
3D/Пластина.stl
36.5 x 3.00 x 45.5

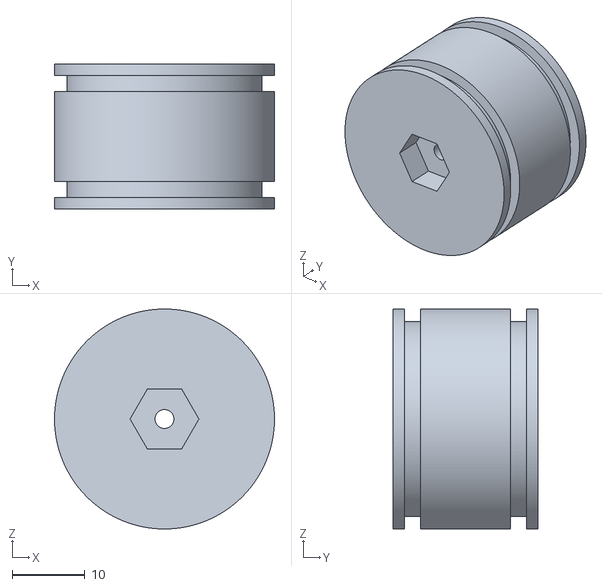
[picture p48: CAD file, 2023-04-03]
3D/Колесо.stl
30.3 x 20.0 x 30.3

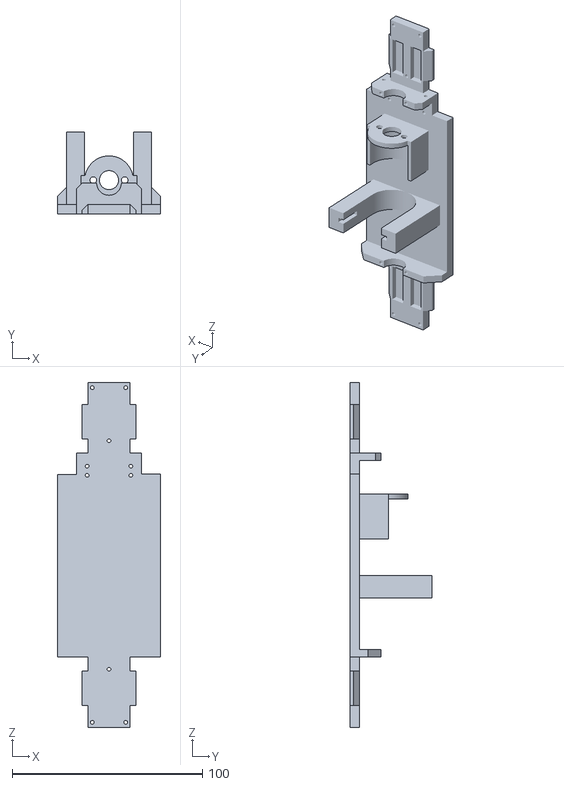
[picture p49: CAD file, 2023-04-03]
3D/Основа(Нижний этаж).stl
54.0 x 43.0 x 181.3

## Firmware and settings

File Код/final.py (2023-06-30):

# обьявление нужных библиотек
import cv2, time
import RobotAPI as rapi
import numpy as np
import serial

# Создаем обьект камеры
robot = rapi.RobotAPI(flag_serial=False)
robot.set_camera(100, 640, 480)
port = serial.Serial('/dev/ttyS0', baudrate=115200, stopbits=serial.STOPBITS_ONE)

# Обьявляем перемнные
fps = 0
fps1 = 0
fps_time = 0
btntime = time.time()
znaktime = time.time()
dl = 0
dr = 0
xz = 0
yz = 0
hz = 0
wz = 0
xo = 0
line = 'None'
colorz = "None"
color1 = 0
inn = ''

servo = 0
rgb = '010'
start_message = '999999999$'
message = ''
btn = 1
eold = 1
eold1 = 1
line_orange, line_blue = 0, 0
circle = 0
direct = "None"
sum = 0
flag_povorot = False
state = 0
time_state = time.time()

stop_time = 0
stop = [0, 0, 0, 0]
index = 1
stop_flag = True
dlm = [0] * 20
drm = [0] * 20

time_line = time.time()
time_stop = time.time()
time_data = time.time()

index_cube = 0
index_place = 0
list_cube = [["", "", ""], ["", "", ""], ["", "", ""], ["", "", ""]]
list_flag = True
list_time = time.time()

cube_color = "None"
cube_time = time.time()
cube_flag = False
index_time = time.time()
flag_pov = False
last_cube_time = 0
pl_time = 0
pl_list = [[0, 0, 0], [0, 0, 0], [0, 0, 0], [0, 0, 0]]
pl_index_place = 0
pl_index_time = 0
pl_flag = False
p = 1

state_state = 0
# обьявляем массивы hsv для оранжевого голубого и черного
lowr = np.array([0, 89, 46])
upr = np.array([11, 255, 255])
# lowr = np.array([0, 66, 69])
# upr = np.array([8, 255, 255])

# lowg=np.array([ 66, 150,  52])
# upg=np.array( [ 83, 255, 255])
lowg = np.array([67, 229, 52])
upg = np.array([81, 255, 254])

# lowor = np.array([7, 110, 64])
# upor = np.array([21, 255, 255])
lowor = np.array([9, 100, 100])
upor = np.array([30, 255, 255])

# lowblue = np.array([82, 63, 0])
# upblue = np.array([180, 255, 255])
lowblue = np.array([84, 63, 0])
upblue = np.array([180, 255, 255])

lowblack = np.array([0, 0, 0])
# upblack = np.array([180, 255, 30])
upblack = np.array([180, 255, 40])

speed = 70

# Функция отвечает вывод на изображение необходимых для нас переменных, за изменением которых нам нужно следить
def telemetria(frame):
    # объявляем глобальные переменные
    global fps, xz, yz, line, dl, dr, colorz, servo, circle, dl, dr, list_cube, list_flag, last_cube_time
    # поочередно выводим на экран нужные нам значения

    # cv2.putText(frame, str(index_cube) + str(circle), (0,60), cv2.FONT_HERSHEY_COMPLEX_SMALL, 1, (255, 255, 255), 2)
    # cv2.putText(frame, str("time=") + str(round(pl_time,2)), (0, 40), cv2.FONT_HERSHEY_COMPLEX_SMALL, 1, (255, 255, 255), 2)
    # cv2.putText(frame, str("flag=") + str(pl_list[3]), (0, 80), cv2.FONT_HERSHEY_COMPLEX_SMALL, 1, (255, 255, 255), 2)
    # cv2.putText(frame, str("") + str(list_cube[2]), (280, 60), cv2.FONT_HERSHEY_COMPLEX_SMALL, 1, (255, 255, 255), 2)
    # cv2.putText(frame, str("") + str(list_cube[1]), (280, 40), cv2.FONT_HERSHEY_COMPLEX_SMALL, 1, (255, 255, 255), 2)
    # cv2.putText(frame, str("list=") + str(list_cube[0]), (280, 20), cv2.FONT_HERSHEY_COMPLEX_SMALL, 1, (255, 255, 255),2)
    # cv2.putText(frame, str("") + str(list_cube[3]), (280, 80), cv2.FONT_HERSHEY_COMPLEX_SMALL, 1, (255, 255, 255), 2)
    # cv2.putText(frame, str(pl_list), (0, 100), cv2.FONT_HERSHEY_COMPLEX_SMALL, 1, (255, 255, 255), 2)
    cv2.putText(frame, str(message), (0, 20), cv2.FONT_HERSHEY_COMPLEX_SMALL, 1, (255, 255, 255), 2)
    cv2.putText(frame, str("fps=") + str(fps), (490, 20), cv2.FONT_HERSHEY_COMPLEX_SMALL, 1, (255, 255, 255), 2)
    # cv2.putText(frame, str("") + str(list_cube[3]), (300, 40), cv2.FONT_HERSHEY_COMPLEX_SMALL, 1, (255, 255, 255), 2)
    cv2.putText(frame, str("") + str(cube_color), (300, 60), cv2.FONT_HERSHEY_COMPLEX_SMALL, 1, (255, 255, 255), 2)
    cv2.putText(frame, str("servo") + str(servo), (300, 80), cv2.FONT_HERSHEY_COMPLEX_SMALL, 1, (255, 255, 255), 2)

    cv2.putText(frame, str("direct=") + str(direct), (300, 100), cv2.FONT_HERSHEY_COMPLEX_SMALL, 1, (255, 255, 255), 2)


# функция, которая отвечает за нахождение контуров знаков (красных и зеленых)
def datz(frame):
    # объявляем глобальные переменные
    global lowr, upr, lowg, upg, colorz, xz, yz, hz, wz, znaktime, color1, index_cube, index_place, list_cube, list_flag, cube_time, cube_color, cube_time, cube_flag, index_time, flag_pov, pl_time, pl_index_time, pl_index_place, pl_flag, stop
    # задаем область интереса для нашего датчика
    # dz=frame[190:380, 100:540]
    dz = frame[200:350, 120:520]
    hsv = cv2.cvtColor(dz, cv2.COLOR_BGR2HSV)
    # Ищем зеленый цвет
    maskg = cv2.inRange(hsv, lowg, upg)
    # Находим контуры зеленого
    imd1, contoursd1, hod1 = cv2.findContours(cv2.blur(maskg, (3, 3)), cv2.RETR_TREE, cv2.CHAIN_APPROX_NONE)
    w_g = 0
    h_g = 0
    x_g = 0
    y_g = 0
    # Отбираем подходящие по размеру контуры
    for contorb1 in contoursd1:
        x, y, w, h = cv2.boundingRect(contorb1)
        if w * h > 700 and y + h > y_g + h_g:
            w_g = w
            h_g = h
            x_g = x
            y_g = y

    # Ищем красный цвет
    maskr = cv2.inRange(hsv, lowr, upr)
    # Находим контуры красногго
    imd1, contoursd1, hod1 = cv2.findContours(cv2.blur(maskr, (3, 3)), cv2.RETR_TREE, cv2.CHAIN_APPROX_NONE)
    w_r = 0
    h_r = 0
    x_r = 0
    y_r = 0
    # Ищем подходящие по размерам контуры
    for contorb1 in contoursd1:
        x, y, w, h = cv2.boundingRect(contorb1)
        # выделяем самый большой контур
        if w * h > 700 and y + h > y_r + h_r:
            w_r = w
            h_r = h
            x_r = x
            y_r = y

    # Если не увидели знак, то цвет = None
    if h_r == 0 and h_g == 0:
        if znaktime + 0.05 < time.time():
            colorz = "None"
            xz, yz, wz, hz = 0, 0, 0, 0
        if znaktime + 0.5 < time.time():
            color1 = "None"
    # Если нашли контуры нужного цвета
    else:
        # Задаем таймер для увиденного знака
        znaktime = time.time()
        # Если увидели оба знака
        if h_r > 0 and h_g > 0:
            # Выбираем тот, контур которого больше
            if y_r + h_r > y_g + h_g:
                colorz = "red"
                # Обводим его контур
                cv2.rectangle(dz, (x_r, y_r), (x_r + w_r, y_r + h_r), (0, 255, 0), 2)
                xz, yz, wz, hz = x_r, y_r, w_r, h_r
                if yz + hz > 50:
                    color1 = colorz
            else:
                colorz = "green"
                # Обводим его контур
                cv2.rectangle(dz, (x_g, y_g), (x_g + w_g, y_g + h_g), (0, 0, 255), 2)
                xz, yz, wz, hz = x_g, y_g, w_g, h_g
                if yz + hz > 50:
                    color1 = colorz
        # Если увидели только один знак
        else:
            # Красный
            if h_r > 0:
                colorz = "red"
                cv2.rectangle(dz, (x_r, y_r), (x_r + w_r, y_r + h_r), (0, 255, 0), 2)
                xz, yz, wz, hz = x_r, y_r, w_r, h_r
                if yz + hz > 50:
                    color1 = colorz
            # Зеленый
            if h_g > 0:
                colorz = "green"
                cv2.rectangle(dz, (x_g, y_g), (x_g + w_g, y_g + h_g), (0, 0, 255), 2)
                xz, yz, wz, hz = x_g, y_g, w_g, h_g
                if yz + hz > 50:
                    color1 = colorz
    if yz + hz > 130 and cube_time + 1 < time.time() and circle < 8:
        cube_time = time.time()
        cube_color = colorz
        cube_flag = True
        if colorz != "None" and direct != "None" and list_flag == True and circle < 5 and pl_flag == False:
            pl_time = cube_time - time_line
            pl_list[pl_index_place][pl_index_time] = round(pl_time, 2)
            pl_index_time += 1
            if pl_index_time > 2:
                pl_index_place += 1
                pl_index_time = 0
                if pl_index_place > 3:
                    pl_index_place = 0
            list_cube[index_cube][index_place] = colorz
            index_place += 1
            if index_place > 2:
                index_cube += 1
                index_place = 0

    if flag_pov == True and pl_flag == False:
        index_cube += 1
        index_place = 0
        pl_index_place += 1
        pl_index_time = 0
        flag_pov = False
        if index_cube == 4:
            index_cube = 0
        if pl_index_place == 4:
            pl_index_place = 0
    if circle == 5:
        pl_flag = True

    if pl_flag == True:
        for i in range(0, 4):
            if list_cube[i][0] != '' and list_cube[i][1] != '':
                list_cube[i][2] = list_cube[i][1]
                list_cube[i][1] = ""
            elif list_cube[i][0] != '':
                if pl_list[i][0] > 0.33 * stop[i] and pl_list[i][0] < 0.66 * stop[i]:
                    list_cube[i][1] = list_cube[i][0]
                    list_cube[i][0] = ''
                if pl_list[i][0] > 0.66 * stop[i]:
                    list_cube[i][2] = list_cube[i][0]
                    list_cube[i][0] = ''
        pl_flag = 2
    if colorz == "None" and pl_flag == False:
        list_flag = True

    # Отрисовываем рамку, в области которой работает наш датчик


# Функция отвечает за нахождение черных контуров на левом датчике
def dlz(frame):
    global dl, dlm
    # Разбиваем датчик на отдельные маленькие кусочки, и на каждом ищем черный
    for i in range(0, 260, 13):
        dblz = frame[230:270, i:(i + 13)]
        hsv = cv2.cvtColor(dblz, cv2.COLOR_BGR2HSV)
        mask_black1 = cv2.inRange(hsv, lowblack, upblack)
        mask_blue = cv2.bitwise_not(cv2.inRange(hsv, lowblue, upblue))
        m = cv2.bitwise_and(mask_black1, mask_blue)
        imd1, contoursd1, hod1 = cv2.findContours(m, cv2.RETR_TREE, cv2.CHAIN_APPROX_NONE)
        x1, y1, h1, w1 = 0, 0, 0, 0
        # находим черные контуры#находим черные контуры
        dlm[i // 13] = 0
        for contorb1 in contoursd1:
            x, y, w, h = cv2.boundingRect(contorb1)
            a1 = cv2.contourArea(contorb1)
            # выделяем самый большой контур
            if x + w > x1 + w1 and a1 > 40 and h > 20:
                x1, w1, y1, h1 = x, w, y, h
                dlm[i // 13] = 1
                # cv2.rectangle(frame, (i, 230), ((i + 13), 270), (255, 255, 255), -1)
    # Высчитываем значение датчика
    dl = 0
    for i in range(20):
        if dlm[19 - i] == 1:
            dl = 20 - i
            break

    # cv2.rectangle(frame, (0, 230), (200, 290), (255, 0, 0), 2)


# Функция отвечает за нахождение черных контуров на правом датчике
# Функция отвечает за нахождение черных контуров на правом датчике
def drz(frame):
    global dr, drm
    # Разбиваем датчик на отдельные маленькие кусочки, и на каждом ищем черный
    for i in range(0, -260, -13):
        dbrz = frame[230:270, 640 + i - 13:640 + i]
        hsv = cv2.cvtColor(dbrz, cv2.COLOR_BGR2HSV)
        mask_black = cv2.inRange(hsv, lowblack, upblack)
        mask_blue = cv2.bitwise_not(cv2.inRange(hsv, lowblue, upblue))
        m = cv2.bitwise_and(mask_black, mask_blue)
        imd1, contoursd1, hod1 = cv2.findContours(m, cv2.RETR_TREE, cv2.CHAIN_APPROX_NONE)
        x1, y1, h1, w1 = 0, 0, 0, 0
        # находим черные контуры#находим черные контуры
        drm[((200 + i) // 13) - 1] = 0
        for contorb1 in contoursd1:
            x, y, w, h = cv2.boundingRect(contorb1)
            a1 = cv2.contourArea(contorb1)
            # выделяем самый большой контур
            if x + w > x1 + w1 and a1 > 40 and h > 20:
                x1, w1, y1, h1 = x, w, y, h
                drm[((200 + i) // 13) - 1] = 1
                # cv2.rectangle(frame, ((640 + i - 13), 230), ((640 + i), 270), (255, 255, 255), -1)
    # Высчитываем значение датчика
    dr = 0
    for i in range(20):
        if drm[i] == 1:
            dr = 20 - i
            break

    # cv2.rectangle(frame, (440, 230), (640, 290), (255, 0, 0), 2)


# Функция отвечает за движене робота на основе регулятора
def pd():
    global dr, dl, servo, eold, direct
    # находим ошибку
    e = dl - dr
    if -1 <= e <= 1:
        e = 0
    # обьявляем коэффициент
    kp = 3
    kd = 2.5
    # используем формулу пд регулятора
    servo = kp * e + kd * (e - eold)
    # записываем старую ошибку
    eold = e
    # предохраниние от резких поворотов
    if servo > 60:
        servo = 60
    if servo < -60:
        servo = -60
    # если датчики не видят черных контуров
    if dl == 0 and dr > 2:
        servo = -40
    if dr == 0 and dl > 2:
        servo = 40
    # находим направение нашего робота
    if dr == 0 and dl == 0:
        if direct == "blue":
            servo = -50
        if direct == "orange":
            servo = 50

    # Условия для объезда сложных препятствий
    if direct == "blue" and color1 == 'red':
        if time_data + 0.2 > time.time():
            servo = -60
    if direct == "orange" and color1 == 'green':
        if time_data + 0.2 > time.time():
            servo = 60


def pdl():
    global dr, dl, servo, eold, direct, dlm, drm, max_servo

    # находим ошибку
    e = dl - 8
    if -1 <= e <= 1:
        e = 0
    # обьявляем коэффициент
    kp = 5
    kd = 1
    # используем формулу пд регулятора
    servo = kp * e + kd * (e - eold)
    # записываем старую ошибку
    eold = e


def pdr():
    global dr, dl, servo, eold, direct, dlm, drm, max_servo

    # находим ошибку
    e = 8 - dr
    if -1 <= e <= 1:
        e = 0
    # обьявляем коэффициент
    kp = 3
    kd = 0.4
    # используем формулу пд регулятора
    servo = kp * e + kd * (e - eold)
    # записываем старую ошибку
    eold = e
    # предохраниние от резких поворотов

# Функция для объезда красного знака
def pdzr():
    global xz, yz, wz, hz, servo, eold1
    # рассчет перспективы
    xo = 230 - (yz + hz) * 1.1
    # Высчитываем ошибку
    e = (xz + wz) - xo
    k = 0.3
    # Находим нужный угол поворота
    servo = k * e + 0.2 * (e - eold1)
    eold1 = e


# Функция для объезда зеленого знака
def pdzg():
    global xz, yz, wz, hz, servo, eold1
    # рассчет перспективы
    xo = 170 + (yz + hz) * 1.1
    # Высчитываем ошибку
    e = xz - xo
    k = 0.3
    # Находим нужный угол поворота
    servo = k * e + 0.2 * (e - eold1)
    eold1 = e


# Функция отвечает за остановку робота и за счет кругов
def dlin(frame):
    global lowor, upor, line, upblue, lowblue, line_orange, line_blue, direct, circle, time_line, stop, stop_flag, stop_time, index, cube_flag, cube_time, last_cube_time, flag_pov, last_cube_time
    line = 'None'
    # условие если оранжевые или голубые контуры не найдены, находим направление движения нашего робота
    if direct == "None":
        x, y, w, h = 0, 0, 0, 0
        # выделяем область интереса
        linz = frame[380:420, 295:345]
        # накладываем серую маску на наше изображение для нахождения оранжевых контуров
        hsv = cv2.cvtColor(linz, cv2.COLOR_BGR2HSV)
        mask_orange = cv2.inRange(hsv, lowor, upor)
        imd1, contoursd1, hod1 = cv2.findContours(cv2.blur(mask_orange, (3, 3)), cv2.RETR_TREE, cv2.CHAIN_APPROX_NONE)
        # поиск оранжевых контуров
        for contorb1 in contoursd1:
            x, y, w, h = cv2.boundingRect(contorb1)
            if w * h > 70:
                line_orange += 1
                line = 'orange'
                direct = "orange"
        # накладываем серую маску на наше изображение для нахождения голубых контуров
        mask_blue = cv2.inRange(hsv, lowblue, upblue)
        imd1, contoursd1, hod1 = cv2.findContours(cv2.blur(mask_blue, (3, 3)), cv2.RETR_TREE, cv2.CHAIN_APPROX_NONE)
        # поиск голубых контуров
        for contorb1 in contoursd1:
            x, y, w, h = cv2.boundingRect(contorb1)
            if w * h > 80:
                line = 'blue'
                direct = "blue"
                line_blue += 1
        # оюводим найденные контуры
        cv2.rectangle(linz, (x, y), (x + w, y + h), (0, 255, 0), 2)

        # if direct != "None":
        #     flag_pov = True
        #     if cube_flag == True and circle < 8:
        #         last_cube_time = time.time() - cube_time
        #         cube_flag = False
        #     circle += 1
        #     time_line = time.time()
    # если контуры уже найдены и известно направление робота
    else:
        # если первым контуром попался голубой
        if direct == "blue":
            x, y, w, h = 0, 0, 0, 0
            # обьявление области интереса
            linz = frame[380:420, 295:345]
            hsv = cv2.cvtColor(linz, cv2.COLOR_BGR2HSV)
            mask_blue = cv2.inRange(hsv, lowblue, upblue)
            imd1, contoursd1, hod1 = cv2.findContours(cv2.blur(mask_blue, (3, 3)), cv2.RETR_TREE,
                                                cv2.CHAIN_APPROX_NONE)
            # поиск контуров
            for contorb1 in contoursd1:
                x, y, w, h = cv2.boundingRect(contorb1)
                if w * h > 80:
                    line = 'blue'
            # обводим найденные контуры
            cv2.rectangle(linz, (x, y), (x + w, y + h), (0, 255, 0), 2)
            # условие считает круги
            if line == "blue" and time_line + 0.5 < time.time():
                # записываем круг

                if cube_flag == True and circle < 8:
                    last_cube_time = time.time() - cube_time
                    cube_flag = False
                flag_pov = True
                circle += 1
                # в массив записываем средние значение проезда круга
                if circle < 8:
                    stop[index] = round(time.time() - time_line, 2)
                    index += 1

                    # ибнуляем индекс и записываем в массив значенияпо новой
                    if index == 4:
                        index = 0
                time_line = time.time()

        # если первым контуром попался оранжевый
        if direct == "orange":
            x, y, w, h = 0, 0, 0, 0
            # выделяем область интереса
            linz = frame[380:420, 295:345]
            hsv = cv2.cvtColor(linz, cv2.COLOR_BGR2HSV)
            mask_orange = cv2.inRange(hsv, lowor, upor)
            imd1, contoursd1, hod1 = cv2.findContours(cv2.blur(mask_orange, (3, 3)), cv2.RETR_TREE,
                                                cv2.CHAIN_APPROX_NONE)
            # находим оранжевые контуры
            for contorb1 in contoursd1:
                x, y, w, h = cv2.boundingRect(contorb1)
                if w * h > 70:
                    line = 'orange'
            # обводим найденные контуры
            cv2.rectangle(linz, (x, y), (x + w, y + h), (0, 255, 0), 2)
            # если увидели оранжевый то считаем круг
            if line == "orange" and time_line + 0.5 < time.time():
                # добавляем один круг

                if cube_flag == True and circle < 8:
                    last_cube_time = time.time() - cube_time
                    cube_flag = False
                flag_pov = True
                circle += 1
                # записывае в массив среднее значения проезда участка
                if circle < 8:
                    stop[index] = round(time.time() - time_line, 2)
                    index += 1

                    # ибнуляем индекс и записываем в массив значенияпо новой
                    if index == 4:
                        index = 0
                time_line = time.time()
    # обводим область интереса
    # cv2.rectangle(frame, (295, 380), (345, 420), (0, 0, 0), 2)

# Функция отвечающая за разворот
def razvorot():
    global flag_povorot, state, speed, servo, direct, time_state, circle, p
    p = 1
    flag_povorot = True
    if direct == 'orange':
        p = -1
    if state == 0:
        speed = 0
        time_state = time.time()
        state = 1

    # Разворот ближе к внутреннему бортику
    if direct == 'orange' or (direct == 'blue' and last_cube_time > 1):



        if state == 1:
            servo = 45 * p
            speed = 30
            if time_state + 2.5 < time.time():
                state = 2
                time_state = time.time()
        if state == 2:
            servo = -50 * p
            speed = -30
            if time_state + 2 < time.time():
                state = 3
                speed = 0
                time_state = time.time()
        if state == 3:
            de = 0
            if last_cube_time < 1:
                de = 0.2
                speed = -30
                servo = 0
            else:
                de = 2
                speed = 30
                dlz(frame)
                pdl()

            if time_state + de < time.time():
                flag_povorot = False
                if p == 1:
                    direct = 'orange'
                else:
                    direct = 'blue'
                circle += 1
                state = 4
                speed = 60

    # Разворот ближе к внешнему бортику
    else:

        if state == 1:
            servo = -45
            speed = 30
            if time_state + 1.3 < time.time():
                state = 2
                time_state = time.time()
        if state == 2:
            servo = 50
            speed = -30
            if time_state + 1.2 < time.time():
                state = 3
                speed = 0
                time_state = time.time()
        if state == 3:
            servo =0
            if last_cube_time < 2:
                speed = -30
            else:
                speed = 30
            if time_state + 1 < time.time():
                flag_povorot = False
                if p == 1:
                    direct = 'orange'
                else:
                    direct = 'blue'
                circle += 1
                state = 4
                speed = 60

port.reset_input_buffer()
# цикл проигрывает наши функции
start = False
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

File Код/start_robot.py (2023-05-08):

# pyinstaller --onefile --noconsole start_robot.py
__author__ = 'Yuri Glamazdin <yglamazdin@gmail.com>'
__version__ = '1.6'

import json
import os
import socket as sc
import threading
import time
import tkinter.filedialog as tkFileDialog
import tkinter as tk
import cv2
import numpy as np
import zmq
import zlib
import base64
import InetConnection as InetConnection
# Create a UDP socket
import select

from ctypes import *
from ctypes.util import find_library
import platform
import numpy as np
import math
import warnings
import os
import pickle, base64

flag_udp_comand = False
flag_udp_event = False
flag_udp_turbo_show_window = False
flag_udp_show_window = False

show_system_message = False
fps_fix_timer = 0.04


video_show = 0
video_show2 = 3
video_show2_global = 0
video_show2_global = 0
video_show_work = False
flag_start_script = None
timer_wait_start = 10
lock_time = 10+60 * 30

# default libTurboJPEG library path
DEFAULT_LIB_PATHS = {
    'Darwin': ['/usr/local/opt/jpeg-turbo/lib/libturbojpeg.dylib'],
    'Linux': [
        '/usr/lib/x86_64-linux-gnu/libturbojpeg.so.0',
        '/opt/libjpeg-turbo/lib64/libturbojpeg.so'
    ],
    # 'Windows': ['C:/libjpeg-turbo-gcc64/bin/libturbojpeg.dll']
    'Windows': ['libturbojpeg.dll']
}

# error codes
# see details in https://github.com/libjpeg-turbo/libjpeg-turbo/blob/master/turbojpeg.h
TJERR_WARNING = 0
TJERR_FATAL = 1

# color spaces
# see details in https://github.com/libjpeg-turbo/libjpeg-turbo/blob/master/turbojpeg.h
TJCS_RGB = 0
TJCS_YCbCr = 1
TJCS_GRAY = 2
TJCS_CMYK = 3
TJCS_YCCK = 4

# pixel formats
# see details in https://github.com/libjpeg-turbo/libjpeg-turbo/blob/master/turbojpeg.h
TJPF_RGB = 0
TJPF_BGR = 1
TJPF_RGBX = 2
TJPF_BGRX = 3
TJPF_XBGR = 4
TJPF_XRGB = 5
TJPF_GRAY = 6
TJPF_RGBA = 7
TJPF_BGRA = 8
TJPF_ABGR = 9
TJPF_ARGB = 10
TJPF_CMYK = 11

# chrominance subsampling options
# see details in https://github.com/libjpeg-turbo/libjpeg-turbo/blob/master/turbojpeg.h
TJSAMP_444 = 0
TJSAMP_422 = 1
TJSAMP_420 = 2
TJSAMP_GRAY = 3
TJSAMP_440 = 4
TJSAMP_411 = 5

# miscellaneous flags
# see details in https://github.com/libjpeg-turbo/libjpeg-turbo/blob/master/turbojpeg.h
# note: TJFLAG_NOREALLOC cannot be supported due to reallocation is needed by PyTurboJPEG.
TJFLAG_BOTTOMUP = 2
TJFLAG_FASTUPSAMPLE = 256
TJFLAG_FASTDCT = 2048
TJFLAG_ACCURATEDCT = 4096
TJFLAG_STOPONWARNING = 8192
TJFLAG_PROGRESSIVE = 16384


class TurboJPEG(object):
    """A Python wrapper of libjpeg-turbo for decoding and encoding JPEG image."""

    def __init__(self, lib_path=None):
        turbo_jpeg = cdll.LoadLibrary(
            self.__find_turbojpeg() if lib_path is None else lib_path)
        self.__init_decompress = turbo_jpeg.tjInitDecompress
        self.__init_decompress.restype = c_void_p
        self.__init_compress = turbo_jpeg.tjInitCompress
        self.__init_compress.restype = c_void_p
        self.__destroy = turbo_jpeg.tjDestroy
        self.__destroy.argtypes = [c_void_p]
        self.__destroy.restype = c_int
        self.__decompress_header = turbo_jpeg.tjDecompressHeader3
        self.__decompress_header.argtypes = [
            c_void_p, POINTER(c_ubyte), c_ulong, POINTER(c_int),
            POINTER(c_int), POINTER(c_int), POINTER(c_int)]
        self.__decompress_header.restype = c_int
        self.__decompress = turbo_jpeg.tjDecompress2
        self.__decompress.argtypes = [
            c_void_p, POINTER(c_ubyte), c_ulong, POINTER(c_ubyte),
            c_int, c_int, c_int, c_int, c_int]
        self.__decompress.restype = c_int
        self.__compress = turbo_jpeg.tjCompress2
        self.__compress.argtypes = [
            c_void_p, POINTER(c_ubyte), c_int, c_int, c_int, c_int,
            POINTER(c_void_p), POINTER(c_ulong), c_int, c_int, c_int]
        self.__compress.restype = c_int
        self.__free = turbo_jpeg.tjFree
        self.__free.argtypes = [c_void_p]
        self.__free.restype = None
        self.__get_error_str = turbo_jpeg.tjGetErrorStr
        self.__get_error_str.restype = c_char_p
        # tjGetErrorStr2 is only available in newer libjpeg-turbo
        self.__get_error_str2 = getattr(turbo_jpeg, 'tjGetErrorStr2', None)
        if self.__get_error_str2 is not None:
            self.__get_error_str2.argtypes = [c_void_p]
            self.__get_error_str2.restype = c_char_p
        # tjGetErrorCode is only available in newer libjpeg-turbo
        self.__get_error_code = getattr(turbo_jpeg, 'tjGetErrorCode', None)
        if self.__get_error_code is not None:
            self.__get_error_code.argtypes = [c_void_p]
            self.__get_error_code.restype = c_int
        self.__scaling_factors = []

        class ScalingFactor(Structure):
            _fields_ = ('num', c_int), ('denom', c_int)

        get_scaling_factors = turbo_jpeg.tjGetScalingFactors
        get_scaling_factors.argtypes = [POINTER(c_int)]
        get_scaling_factors.restype = POINTER(ScalingFactor)
        num_scaling_factors = c_int()
        scaling_factors = get_scaling_factors(byref(num_scaling_factors))
        for i in range(num_scaling_factors.value):
            self.__scaling_factors.append(
                (scaling_factors[i].num, scaling_factors[i].denom))

    def decode_header(self, jpeg_buf):
        """decodes JPEG header and returns image properties as a tuple.
           e.g. (width, height, jpeg_subsample, jpeg_colorspace)
        """
        handle = self.__init_decompress()
        try:
            width = c_int()
            height = c_int()
            jpeg_subsample = c_int()
            jpeg_colorspace = c_int()
            jpeg_array = np.frombuffer(jpeg_buf, dtype=np.uint8)
            src_addr = self.__getaddr(jpeg_array)
            status = self.__decompress_header(
                handle, src_addr, jpeg_array.size, byref(width), byref(height),
                byref(jpeg_subsample), byref(jpeg_colorspace))
            if status != 0:
                self.__report_error(handle)
            return (width.value, height.value, jpeg_subsample.value, jpeg_colorspace.value)
        finally:
            self.__destroy(handle)
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

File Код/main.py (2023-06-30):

from pyb import delay, Pin, ADC, Timer
import pyb
from machine import UART

uart = UART(6, 115200, stop=1)
btn = Pin('Y7', Pin.IN, Pin.PULL_UP)
servo1 = pyb.Servo(1)
p1 = Pin('Y9')
in_b = Pin('Y10', Pin.OUT_PP)
in_a = Pin('Y11', Pin.OUT_PP)

l_r = Pin('Y5', Pin.OUT_PP)
l_b = Pin('Y4', Pin.OUT_PP)
l_g = Pin('Y3', Pin.OUT_PP)

in_a.high()
in_b.low()
tim = Timer(2, freq=10000)
ch1 = tim.channel(3, Timer.PWM, pin=p1)
inn = ''
speed = 0
serv = 10
servo1.angle(serv)
r = 0
g = 0
b = 0
f = 0


def rgb(r,g,b):
    if r == 1:
        l_r.low()
    else:
        l_r.high()

    if g == 1:
        l_g.low()
    else:
        l_g.high()

    if b == 1:
        l_b.low()
    else:
        l_b.high()

def motor(sped):
    global in_a, in_b, ch1
    if sped > 0:
        in_a.low()
        in_b.high()
        ch1.pulse_width_percent(sped)
    else:
        in_b.low()
        in_a.high()
        ch1.pulse_width_percent(abs(sped))

rgb(1,1,1)
start = False

while True:
    # print(btn.value())
    if uart.any():
        # pyb.LED(3).on()
        a = chr(uart.readchar())
        if a != '$':
            inn = inn + a
            if len(inn) > 10:
                inn = ''
        else:
            try:
                if len(inn) == 9:
                    # pyb.LED(4).on()
                    # print(inn)
                    if not start:
                        if inn == '999999999':
                            rgb(0, 1, 0)
                        if btn.value() == 0:
                            start = True
                    else:
                        if inn != '999999999':
                            speed = int(inn[0:3]) - 200
                            serv = int(inn[3:6]) - 200 + 10
                            r = int(inn[6])
                            g = int(inn[7])
                            b = int(inn[8])
                            # inn = ''
                            # print(speed, serv, r, g, b)
                            if serv>60:serv = 60
                            if serv < -60: serv = -60
                            servo1.angle(serv)
                            motor(speed)
                            rgb(r,g,b)
            except ValueError:
                print('err')
        uart.write(str(btn.value()) + '$')
        # pyb.LED(3).off()

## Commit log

2023-04-03 Create Фото
2023-04-03 Create тест
2023-05-12 Update and rename тест to ссылка на видео Youtube
